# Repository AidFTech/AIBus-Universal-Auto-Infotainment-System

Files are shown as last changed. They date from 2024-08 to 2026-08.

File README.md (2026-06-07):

# AidF AIBus Universal Car Audio System

***Disclaimer:*** *"AIBus" refers to the bus standard used by the devices in this project to communicate with each other. It is a play on words of AidF and BMW IBus. This project does not use or contain any material created by artificial intelligence.*

The goal of this project is to create a more or less universal car stereo system with the ability to retain all external OEM features, such as CD changers, Sirius tuners, and non-radio displays (e.g. audio screens on the cluster). It adds Apple CarPlay and Android Auto through a Carlinkit for music and navigation. At the heart of this system is the AIBus interface, based heavily on BMW's IBus, to allow all components to communicate with each other. The principal components, which can be used in any vehicle, are the Raspberry Pi navigation computer and the Arduino radio tuner. The screen is a separate module and may be vehicle-specific or universal. All vehicle-specific/OEM components communicate with the system via one or more translator modules.

This is an ongoing project and I am a relatively new embedded programmer- any tips would be appreciated!

Thanks to Ted and [Bluebus](https://github.com/tedsalmon/BlueBus.git) for the inspiration!

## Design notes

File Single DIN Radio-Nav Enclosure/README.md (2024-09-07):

# Single DIN Radio/Nav Enclosure

Single-DIN enclosure for the radio, phone module, and Raspberry Pi nav computer.

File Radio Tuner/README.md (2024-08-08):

# AidF AIBus Radio Tuner
The universal radio tuner and source switch. Identified with AIBus ID 0x10. When finished, this device will be able to switch and output analog or digital audio from any source in the car. Full-range FM and AM tuning is supported via the Skyworks Si4732 with the option for 12 FM an 6 AM presets.

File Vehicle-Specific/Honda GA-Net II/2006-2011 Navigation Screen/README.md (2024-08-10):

# 2006-2011 Navigation Screen
This component uses the base, tilt motor, and button pannel of the navigation screen from a 2006-2011 Civic for a monitor. It will fit in any vehicle with a double-DIN opening, and allows for an audio accessory (e.g. CD changer or tape deck) in the top DIN slot, revealed by the screen tilting forward.

***This component is still a work in progress.***

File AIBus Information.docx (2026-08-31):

# AidF AIBus

# Basics

AIBus works similar to BMW’s I-BUS, but is balanced and runs at 115200. The structure is virtually identical.

The structure is as follows:

- Source Device ID: 1B, ID of the source device.
- Length: 1B, includes all following bytes.
- Destination Device ID: 1B, ID of the destination device (0xFF if broadcast).
- Data: Length given in the Length bytes, message.
- XOR Checksum: 1B, a simple XOR of all bytes in the message.

# Radio

  ID 0x10
  Messages:

Source | Length | Destination | Data Example | Interpretation
10 | 3 | FF | 04 E6 10 | Sent to all audio devices when the radio is first connected. May also be sent to individual sources as a “repeat.”
Any | 3 | 10 | 01 01 xx | Audio device “handshake.” Similar to Honda’s. Byte xx indicates device ID. May have a fourth byte to indicate subsource count.
Any | 2 | 10 | 01 02 | Similar audio device “handshake,” indicates that the device has already made contact but needs to add extra “sub-sources.” (e.g. XM1, XM2)
Any | Varies | 10 | 01 22 nn [...] | Short name of the audio device, sub-source nn.
Any | Varies | 10 | 01 23 nn [...] | Name of the audio device, sub-source nn.
10 | 3 or 4 | Any | 40 10 xx nn | Function change, xx indicates the ID of the device that is selected. A device can also send this message to request control (e.g. if a tape is loaded), the radio will send it back if it is accepted. If the source has multiple modes, nn is the mode.
10 | 3 | Any | 40 01 xx | Tells the source that device xx has text control. This control is automatically relinquished when the source receives a 40 10 message.
Any | 3 or 4 | 10 | 10 10 xx nn | Request for control, i.e. if a tape or disc is loaded.
10 | 3 | Any | 70 10 xx | Redundant heartbeat message to let device xx know it is still the selected source.
Any | 2 | 10 | 60 10 | Request for the currently selected source.
Any | 2 | 10 | 60 11 | Request for the current source with text control.
01, 57 | 2 | 10, 57, 3B | 1D nn | Set whether this device should be sending clock data. If nn is 00, stop sending clock messages. Otherwise: - |01: Start sending clock messages. - |02: Send clock messages but don’t automatically set the clock. - |04: Send clock right now if able and set. - |80: Send messages in 12h format.
Any | 4 | 10 | 33 06 xx yy | Set maximum volume to xx yy.
10 | 4 | 6A | 32 06 xx yy | Change volume to 2B value xx yy.
10 | 4 | 6A | 32 0A xx yy | Change the treble to xx yy.
10 | 4 | 6A | 32 0B xx yy | Change the bass to xx yy.
10 | 4 | 6A | 32 10 xx yy | Change the balance to xx yy- the value is formatted as an int16_t.
10 | 4 | 6A | 32 11 xx yy | Change the fade to xx yy.
1, 7 | 2 | 10 | 71 pp | Screen monitor enabled/disabled. If disabled, the radio should request all controls. Can also be sent to the computer to request the monitor on.

# CD Changer

  ID 0x06
  Messages:

Source | Length | Destination | Data Example | Interpretation
06 | 8 | 10, 11 | 39 00 pp 00 3F 00 dd tt | Disc and track, indicated by dd and tt, respectively. Whether the CD is playing is indicated by pp, pp = 02 if not playing, 09 if playing, 08 if seeking.
06 | 5 | 10, 11 | 3B 00 00 ss ss | Current track time. Bytes ss ss are a 16-bit representation of the total seconds.
06 | Varies | 10, 11 | 23 61 bb [...] | Song title in ASCII. Byte bb indicates the number of bytes per character, 1 or 2.
06 | Varies | 10, 11 | 23 62 bb [...] | Artist name in ASCII, same format as title.
06 | Varies | 10, 11 | 23 63 bb [...] | Album name in ASCII, same format as title.
10 | 3 | 06 | 30 00 00 | Query the CD player for status.
10 | 3 | 06 | 30 01 00 | Trigger pause/resume.
10 | 3 | 06 | 30 03 00 | Trigger normal play (if FF/FR is in use).
10 | 3 | 06 | 38 04 00 | Trigger fast forward.
10 | 3 | 06 | 38 04 01 | Trigger fast reverse.
10 | 3 | 06 | 38 06 0n | Go to disc n.
10 | 3 | 06 | 38 06 10 | Go to the previous disc.
10 | 3 | 06 | 38 06 20 | Go to the next disc.
10 | 3 | 06 | 38 06 0n | Go to disc n.
10 | 3 | 06 | 38 07 nn | Toggle scan mode: - 00: Off - 01: On - 10: Toggle
10 | 3 | 06 | 38 08 nn | Toggle random mode: - 00: Off - 01: Random Disc - 02: Random All - 10: Toggle
10 | 3 | 06 | 38 09 nn | Toggle repeat mode: - 00: Off - 01: Repeat Track - 02: Repeat Disc - 10: Toggle
10 | 3 | 06 | 38 0A 00 | Go to the next track.
10 | 3 | 06 | 38 0A 01 | Go to the previous track.
10 | 3 | 06 | 38 0B nn | Go to track nn.

# Nav Computer

  ID 0x01
  Audio Screen Messages:

Source | Length | Destination | Data Example | Interpretation
10 | 3 | 01, 8E | 26 vv mm | Display a volume bar at the top of the screen showing volume vv out of mm.
10, 8E | 3 | 01 | 27 30 26 | Open the audio window.
10 (or audio source) | 3 | 01 | 20 60 nn | Clear area nn. Use FF to clear all areas. Note, for all 2x messages below, follow with ||10 to refresh the screen.
10 (or audio source) | 3 | 01 | 20 61 nn | Clear subtitle area nn. Use FF to clear all subtitle areas.
10 (or audio source) | 3 | 01 | 20 62 nn | Clear function key nn. Use FF to clear all function keys.
10 (or audio source) | 3 | 01 | 20 6B nn | Clear button nn. Use FF to clear all buttons.
10 (or audio source) | 2 | 01 | 20 6F | Clear the entire audio screen.
10 (or audio source) | Varies | 01, 8E | 22 61 […] | Write text to the headerbar to be displayed briefly. Can also be sent from the navigation computer to the phone mirror.
10 (or audio source) | Varies | 01 | 23 60 nn [...] | Write text to the main area indicated by nn. Only valid if the audio screen is visible.
10 (or audio source) | Varies | 01 | 23 61 nn [...] | Write text to the subtitle area indicated by nn. Only valid if the audio screen is visible.
10 (or audio source) | Varies | 01 | 23 62 nn [...] | Write text to the bottom function key nn. Second nibble indicates button 1-6.
10 (or audio source) | Varies | 01 | 23 6B nn [...] | Write text to on-screen button 1-3. If the text is cleared, the button is unused.
10 (or audio source) | 2 | 01 | 23 6F | Refresh the audio screen.
57 | 3 | 01 | 2 0 0 | Emergency shutdown for the computer.

  Menu Messages:

Source | Length | Destination | Data Example | Interpretation
Any | Varies | 01 | 2B 50 nn ll xx xx yy yy ww ww hh hh […] | Create a new menu with nn rows. Bit 7 is 1 if the menu “loops.” Menu length is defined by ll, x and y coordinates are given by xx and yy. Bytes ww and hh define width and height of each entry. May be followed by the menu title or subtitle.
Any | Varies | 01 | 2B 51 nn […] | Add menu entry at position nn. If the menu has already been defined, this changes the entry.
Any | 3 | 01 | 2B 52 nn | Menu is complete, draw it with nn selected.
Any | Varies | 01 | 2B 53 […] | Change the menu title.
Any | Varies | 01 | 2B 54 nn pp mm ss […] | Add slider at position nn. Slider position is defined as pp out of total mm. Byte ss is 1 if the slider is selected.
01 | Varies | Any | 2B 55 […] | A request for a menu with the specified keyword.
01 | Varies | Any | 2B 56 […] | A request for whether a menu with the specified keyword exists.
Any | 2 | 01 | 2B 56 | A reply to the above.
01 | Varies | Any | 2B 57 […] | A request for a menu with the specified keyword and the name of that menu.
Any | Varies | 01 | 2B 57 […] | A reply to the above.
Any | Varies | 01 | 2B 5A nn ll xx xx yy yy ww ww hh hh […] | Create an audio-related menu defined as above. Note that this does not create a menu to be shown on the normal audio screen, it creates a setting overlay menu.
Any | 2 | 01 | 2B 40 | Clear the menu. Clear an audio menu if 4A.
Any | 2 | 01 | 2B 42 | Query to the nav computer regarding whether a menu can be drawn.
01 | 2 | Any | 2B 40 | The menu was cleared, or a menu cannot be drawn.
01 | 2 | Any | 2B 42 | A menu can be drawn, sent after the destination device sends the same message.
01 | 2 | Any | 2B 45 | Request for the settings menu.
10 or 1 | 2 | Any Source | 2B 4A | Request for the audio menu. Typically, this is sent from 1 to 10, then 10 to the source.
1 | 2 | C8 | 2B 4C | Request for the phone menu.
01 | 3 | Any | 2B 60 nn | Entry nn was selected.
01 | 3 | Any | 2B 6A nn | Main audio screen entry nn was selected.
01 | 3 | C8 | 2B 6C nn | Phone screen entry nn was selected.

  Vehicle Information Messages:

Source | Length | Destination | Data Example | Interpretation
57 | 3 or 4 | 01 or FF | 11 aa bb | Preceded with A1 if sent to FF. Light status, as follows: - Byte aa: - Bit 7: Auto Headlights - Bit 6: Right Turn Signal - Bit 5: Left Turn Signal - Bit 4: Front Fog Lights - Bit 3: Parking Lights - Bit 2: High Beams - Bit 1: Low Beams - Bit 0: DRLs - Byte bb: - Bit 7: Reverse Lights - Bit 6: Rear Fog Lights - Bit 5: Taillights - Bit 4: License Plate Lights - Bit 3: Off Road Lights - Bit 2: Bed Light

Navigation Messages:

Source | Length | Destination | Data Example | Interpretation

  01, 8E
  Varies
  11, 57
  7F 04 en an st sp sr sr […]
  Next turn event. Typically, byte an indicates the turn angle. 00=12:00 and the direction is spun counterclockwise. So a value of 0x40 indicates due left, etc. Byte en indicates the entry angle. Byte st indicates the step number. Byte sp indicates special instructions as follows, in decimal:
- 0: Normal Turn
- 1: Destination
- 2: Toll Booth
- 3: Ferry
- 4: Train
- 5: Enter Traffic Circle
- 6: Leave Traffic Circle, an indicates exit number.
- 7: Enter and leave traffic circle, an indicates exit number.
- 8: Make a U-turn, left
- 9: Make a U-turn, right
- 10: Merge Left
- 11: Merge Right
- 12: Waypoint
  Bytes sr indicate intersection design. Bit 0 of this cluster indicates a street at 12:00, each following bit indicates a street counterclockwise from there.

01, 8E | Varies | 11, 57 | 7F 05 nn rr […] | Next turn distance. Byte nn defines units (normally sent in m, bit 7 is high if km, bit 6 if mi, bit 5 if yd, and bit 4 if ft), and number of decimal places (bits 3-0). Byte rr indicates how to render a navigation bar.
8E | 3 | 01 | 7F 06 pp | Mute/unmute audio for a nav prompt. If pp!=0, mute.

Camera Messages

Source | Length | Destination | Data Example | Interpretation
57, 1 | 3 | 61 | 48 61 nn | Turn the camera on/off, off if nn==0. Otherwise the number determines which camera to use if multiple are present. This message can be sent by 61 to switch the nav system to display the camera.
61 | Varies | 1, 57 | 2C 3B […] | List of supported cameras/features, defined as follows: - 01: Rear View - 02: Left Side View - 03: Right Side View - 04: Front View - 05: Rear View Zoomed - 06: Rear Panoramic - 07: 360° from Top - 08: Bed (truck) - 80: Trajectory - 81: Distance Markers
Any | 2 | 61 | 2C F0 | Request for supported cameras and features.
61 | Varies | 1 | 3C nn […] | Cameras supported in the current view for switching purposes. Byte nn indicates the selected camera.
57 | 2 | 1 | 36 nn | Steering angle for trajectory display. 00 indicates do not display, 80 indicates that the wheel is centered.
57, 61 | 9 | 1 | 37 w1 w1 w2 w2 y1 y1 y2 y2 | Distance/trajectory position. Defined as top width, bottom width, top position, and bottom position. Always centered.
61 | Varies | 1 | 25 57 61 […] | Camera warning message to display at the bottom of the screen. If not specified, the default “Please Check Surroundings for Safety” is used.
61 | Varies | 1 | 25 57 62 […] | Camera video path.

# Screen

ID 0x07

Messages:

Source | Length | Destination | Data Example | Interpretation
07 | 3 | 01 | 30 nn tt | Push or release button nn. Byte tt defines behavior as follows: - 00: Pressed - 40: Held - 80: Released Button Definitions: - 06: Volume Knob - 07: Navigation Knob - 0A: Voice Command - 0B: Phone Send - 0C: Phone End - 11: Preset 1 - 12: Preset 2 - 13: Preset 3 - 14: Preset 4 - 15: Preset 5 - 16: Preset 6 - 20: Home - 21: Eject - 23: Source - 24: Skip Down - 25: Skip Up - 26: Audio - 27: Back - 28: Up - 29: Down - 2A: Left - 2B: Right - 30: FM - 31: AM - 32: Tape - 33: CD - 34: Aux - 35: XM - 36: FM/AM - 37: Tape/CD - 38: Media - 39: Scan - 44: Rewind - 45: FF - 46: Direction - 47: NR - 50: 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
07 | 3 | 01 | 32 nn dt | Knob turned. Byte nn = 06 if volume knob, 07 if navigation knob. Nibble t indicates number of steps, nibble d is 0 if the knob is rotated to the left, 1 if rotated to the right.
07 | 5 | 01 | 35 xx xx yy yy tt | Touch event at xx yy. Byte tt is defined as above.
07 | 2 | 01 | 38 nn | Screen status. Byte nn = 00 if screen is closed, 01 if screen is opening, 02 if open, 03 if closing. FF if the screen cannot move.
01, 10 | 2 | 07 | 38 nn | Byte nn = 0, close the screen. If 2, open the screen.
07 | 4 | 01, 10 | 47 xx yy cc | Auxiliary screen of dimensions xx yy is present. Byte cc is formatted as follows: - Bit 4: RGB Supported - Bit 3: Negative Mode - Bit 2: Dual Mode Supported
01, 10 | Varies | 07 | 27 hh vv […] | Print message to the auxiliary screen in standard monospace at horizontal indentation hh and vertical indentation vv.
01, 10 | Varies | 07 | 2E ss […] | Print message to the auxiliary screen in segmented form. Start at segment ss.
01 | 2 | 07 | 10 pp | Turn off display if pp is 00, on if pp is 11.
Any | 3 | FF | 77 ss nn | A “Status” message sent every 5s. If receiver ID is FF, acknowledgment is not required. If this message stops, all screen controls default to the navigation computer. If nn is ||20, audio controls (volume, preset buttons, source button, and all source controls unless they are requested by another device) are passed from the screen to the sending device (address ss). If ||80, “source” controls are passed to the device (seek/skip, direction control, and rewind/FF, and info). If ||10, all screen controls are passed (can only be sent by the radio).
7 | Varies | Any | 31 30 nn […] | A list of all buttons present on the screen. The bytes sent are the bytes that the buttons would trigger. All devices that can send messages to the screen can receive this message. Byte nn is ||2 if there is a selection wheel present, ||4 if a volume knob is present, ||8 if a tuning knob is present, and ||1 if touch capabilities are present. ||10 if function buttons are in a straight line at the bottom of the screen.
Any | 2 | 7 | 31 30 | A request for the screen buttons.
Any | 4 | 7 | 33 rr nn tt | Request to forward a button message to source rr. State tt and button nn are defined as above.
10 | 2 | 7 | 34 ss | Radio is on/off. Turn AidF logo on/off. Byte ss is 00 if off, 01 if on.
Any | 2 | 7 | 3E F0 | Request for screen EDID data.
7 | 129 | Any | 3E […] | EDID message.

# Custom iMID

ID 0x11

Messages:

Source | Length | Destination | Data Example | Interpretation
11 | 4 | Any | 3B 23 ww hh | Announcement that a custom text field is available, of ww characters per line and hh lines. This message can be sent to FF.
11 | Varies | Any | 3B 57 […] | Announcement that an OEM text field is available. This is followed by the sources available in AIBus form (e.g. 0x10 for radio, etc.).
Any | 3 | 11 | 04 E6 3B | Request for data sent with 3B.
Any | Varies | 11 | 20 60 nn […] | Clear rows indicated by nn. There may be multiple.
Any | Varies | 11 | 23 60 xx yy […] | Write a custom message at space xx and line yy.
10 | 4 | 11 | 40 10 ss uu | Change OEM display to source ss, subsource uu.
11 | 2 | 10 (or source) | 60 11 | A request for the radio to send the source name to the IMID.
11 | 2 | 10 (or source) | 60 10 | A request for the radio to send OEM source data to the IMID.
10 | 6 | 11 | 67 rr rr pp ss hh | FM or AM frequency rr, decimal point position pp. Byte ss is defined as follows: - 0x: Mono - | 1x: Stereo - | 2x: HD1 - | 4x: HD2 - | 6x: HD3 - | 8x: Acquiring HD First nibble defines preset. Byte hh indicates the preceding letter of the frequency in Hz (e.g. 0x4D for M, 0x6B for k).
10 | Varies | 11 | 63 60 […] | Call sign.
10 | Varies | 11 | 63 61 […] | Chunk RDS text.
10 | Varies | 11 | 63 62 […] | Full RDS text.
10 | 3 | 11 | 62 vv mm | Display a volume on screen, vv out of mm. This is sent regardless of the IMID structure.

# Tape Deck

ID 0x13

Messages:

Source | Length | Destination | Data Example | Interpretation
13 | 4 | 10 | 31 pp dd nn | Play status. Byte pp is defined as follows: - 02 = Play - 05 = Rewind - 04 = FF - 07 = Reverse Search - 06 = Forward Search - 10 = Loading - 11 = Ejecting - 00 = Tape Out Byte dd is defined bitwise: - Bit 6: Reverse Mode - Bit 5: Repeat On - Bit 1: NR On - Bit 0: CrO2 tape Byte nn indicates the number of tracks that are being searched. Only read if pp = 07 or 06.
10 | 2 | 13 | 28 00 | Query for tape deck status.
10 | 2 | 13 | 28 01 | Trigger direction change.
10 | 3 | 13 | 28 04 00 | Toggle fast forward.
10 | 3 | 13 | 28 04 01 | Toggle fast reverse.
10 | 4 | 13 | 28 07 00 nn | Toggle forward search. Byte nn indicates the number of tracks that are being searched.
10 | 4 | 13 | 28 07 01 nn | Toggle reverse search. Byte nn indicates the number of tracks that are being searched.
10 | 2 | 13 | 28 09 | Toggle repeat mode.
10 | 2 | 13 | 28 0A | Toggle NR.

# Sirius Tuner

ID 0x19

Messages:

Source | Length | Destination | Data Example | Interpretation
19 | 5 | 10, 11 | 39 00 hh hh pp | The tuner is set to channel hh and preset pp. If pp|=0x80, the signal was lost. If pp|=0x40, the channel is not available.
19 | Varies | 10, 11 | 23 61 bb [...] | Song title in ASCII. Byte bb indicates the number of bits per character, 1 or 2.
19 | Varies | 10, 11 | 23 62 bb [...] | Artist name in ASCII, same format as title.
19 | Varies | 10, 11 | 23 63 bb [...] | Channel name in ASCII, same format as title.
19 | Varies | 10, 11 | 23 64 bb [...] | Genre in ASCII, same format as title.
10 | 2 | 19 | 30 00 | Request for tuner status.
10 | 3 | 19 | 38 04 00 | Go to the next channel.
10 | 3 | 19 | 38 04 01 | Go to the previous channel.
10 | 3 | 19 | 38 05 hh hh | Go to channel hh.
10 | 3 | 19 | 38 06 pp | Go to preset channel pp. Numbers higher than 6 can be used for XM2.
10 | 3 | 19 | 38 07 00 | Increment the preset channel.
10 | 3 | 19 | 38 07 01 | Decrement the preset channel.
10 | 3 | 19 | 38 0A 00 | Go to the next category.
10 | 3 | 19 | 38 0A 01 | Go to the previous category.
10 | 3 | 19 | 38 16 pp | Save current channel as preset pp.

# CANslator

ID 0x57

Messages:

Source | Length | Destination | Data Example | Interpretation
57 | 3 | FF | A1 02 kk | Key position kk. Defined as follows: - 00 = Off - 01 = Acc 1 - 02 = Acc 2 - 03 = Cranking - 04 = Engine On Byte kk is ||10 if the key (or fob) is in the ignition, ||20 if the car has pushbutton start.
57 | 4 | FF | A1 10 ii nn | Illumination brightness, sent every few seconds (or upon change) if the appropriate CAN message is present. Brightness is given as ii, nn is defined as 00 if the system is in day mode, 80 if in night mode; ||1 if illumination should be on.
57 | 4 | FF | A1 11 aa bb | Headlight status, as defined above.
57, 3B, 10 | 6 | FF | A1 1F 01 hh mm ss | Time. Hour, minute, and second. Always 24h. If byte hh is |80, display time as 12h. If |40, time is being set automatically.
57, 3B, 10 | 7 | FF | A1 1F 02 yy yy mm dd | Date. Year, month, date.
57 | Varies | FF | A1 1F 03 nn tt […] | Outside temperature. Byte nn defines units (bit 7 is high if Fahrenheit), number of decimal places (bits 6-4), and number of bytes (bits 2-0). Bit 3 is high if negative.
57 | Varies | FF | A1 1F 04 nn tt […] | Vehicle speed. Byte nn defines units (bit 7 is high if mph), number of decimal places (bits 6-4), and number of bytes (bits 3-0).
57 | Varies | FF | A1 1F 05 nn tt […] | Coolant temperature. Byte nn defines units (bit 7 is high if Fahrenheit), number of decimal places (bits 6-4), and number of bytes (bits 2-0). Bit 3 is high if negative.
57 | Varies | FF | A1 1F 06 nn vv […] | Battery voltage. Byte nn defines number of decimal places (bytes 7-4) and number of bytes (bits 2-0).
57 | Varies | FF | A1 1F 07 nn rr […] | Vehicle range. Byte nn defines units (bit 7 is high if miles), number of decimal places (bits 6-4), and number of bytes (bits 2-0).
57 | Varies | FF | A1 1F 08 nn mm […] | Instantaneous fuel economy. Byte nn defines units (bits 7 and 6 are defined as follows: 11 indicates Imperial mpg, 10 indicates US mpg, 01 indicates km/L, 00 indicates L/100km), bit 5 is high if the fuel economy is undefined, remaining bits define number of decimal places.
57 | Varies | FF | A1 1F 09 nn mm […] | Average fuel economy, defined as above.
57 | Varies | FF | A1 1F 0A nn mm […] | Trip timer. Byte nn defines whether this is given in seconds or minutes- bit 7 is high if minutes. Other bits define byte count.
57 | Varies | FF | A1 1F 0B nn dd […] | Trip distance. Byte nn defines units (bit 7 is high if miles), number of decimal places (bits 6-4), and number of bytes (bits 3-0).
57 | Varies | FF | A1 1F 0C nn ss […] | Cruise set speed. Byte nn defines units (bit 7 is high if mph), number of decimal places (bits 6-4), and number of bytes (bits 3-0). If all zeroes, cruise control is off.
57 | 4 | FF | A1 12 nn gg | Current gear. Byte nn defines the type of transmission: - 00: Manual - 01: Automatic (traditional) - 02: Semiautomatic - 03: DCT/DSG - 04: SMG - 05: CVT - 06: IVT - 07: eCVT - 08: EV Direct Drive - 09: Direct Drive with Engine Clutch (series-parallel hybrid) Byte gg defines the gear- last nibble defines the actual gear number (or ratio percentage with CVT). First nibble: - 0: Neutral - 1: Drive - 2: Reverse - 4: Park - 8: Low Gear - 9: Manual Mode Obviously, for a manual car, only Reverse and Neutral are used.
57 | 3 | FF | A1 13 ss | Signal lights and parking brake. - Bit 0: Left Turn Signal - Bit 1: Right Turn Signal - Bit 2: Hazards Active - Bit 3: Brake Lights - Bit 4: Parking Brake
57 | 3 | FF | A1 14 nn | Auto stop on/off. If nn is nonzero, auto stop is active. If nn is 1, auto stop is disabled.
57 | 5 | FF | A1 33 01 ss xx | Hybrid system is present. Byte ss is defined as follows: - 01: Series Hybrid (e.g. Chevrolet) - 02: Parallel Hybrid (e.g. Honda IMA, Hyundai, Kia) - 03: Series-Parallel Hybrid (e.g. newer Honda) - 04: Power-Split Hybrid (e.g. Ford, Toyota, Nissan) - |10: Charge/Assist Meter Additional features in byte xx: - |01: Plug - |02: Rear Electric Motor - |04: Front Electric Motor (if RWD) - |10: Electric A/C - |20: Conventional A/C - |40: Electric Heater
57 | 6 | FF | A1 33 02 aa bb cc | Hybrid power flow. Byte aa: - |01: Battery to Electric Motor - |02: Electric Motor to Battery - |04: Electric Motor to Battery, regenerative - |08: Electric Motor to Wheels - |10: Wheels to Electric Motor - |20: Engine to Wheels - |40: Engine to Electric Motor - |80: Plug to Battery Byte bb indicates battery charge level out of 255. Byte cc, if present, indicates charge/assist, centered at 0x7F.
57 | 3 | FF | A1 43 dd | Door status. Byte dd is defined as follows: - 20: Hood - 10: Trunk/Liftgate - 08: Driver Door - 04: Front Passenger Door - 02: Left Rear Door - 01: Right Rear Door If the byte |= 0x80, the door is being opened to turn the vehicle off.
01 | 2 | 57 | 45 nn | Request for vehicle information. Byte nn is defined as follows: - 01: Fuel Economy - 02: Odometer - 03: Outside Temperature - 04: Vehicle Speed
57 | Varies | 01 | 46 nn yy […] | Vehicle information with byte nn defined as above. Placed in grid yy- column is defined by bit 7. Row is defined by remaining bits. Contains the string that will be printed to screen.
01 | 2 | 57 | 49 1F | A request for all supported “common” vehicle sensors.
57 | 3 | 01 | 49 aa bb | Supported common parameters. Defined as: Byte aa: - 80: Vehicle Specific Sensors - 8: Remaining Distance - 4: Remaining Time - 2: Trip Distance - 1: Range Byte bb: - 80: Gear - 40: Cruise Speed - 20: Trip Timer - 10: Trip Average Economy - 8: Instantaneous Economy - 4: Coolant Temperature - 2: Outside Temperature - 1: Battery Voltage
Any | 2 | 57 | 4A 18 | A request for key position, doors open, and brightness information to be sent to the sending device upon a change.
Any | 2 | 57 | 4A 1E | A request for info such as key position, doors open, time/date if CANslator is counting, etc. All data is resent.
Any | 2 | 57 | 4A 1F | Similar to above, but sent if the system should assume the sending device has just woken up/is preparing to power off.
57 | 1 | 01 | 4F | Refresh printed data.

# Climate Control Translator

  ID 0x51
  Messages:

Source | Length | Destination | Data Example | Interpretation
51 | 6 | 1 | 25 01 41 tt ff mm | Introductory climate message containing the number of temperature zones (tt), fan zones (ff), and mode zones (mm). Byte 2 is |0x10 if climate control is automatic. For example, a 9th gen Civic would send 25 01 51 01 01 01. An E39 would send 25 01 51 02 01 01, and an E38 would send 25 01 51 02 02 02. Zone 1 is interpreted as the driver’s seat, zone 2 as the passenger, zone 3 as the rear.
51 | 5 | 1 | 25 02 mm xx uu | Minimum (mm) and maximum (xx) temperature. Temperature units uu: 00 if Celsius, 01 if Fahrenheit.
51 | 3 | 1 | 25 03 ff | Number of possible fan speeds.

  51
  Varies
  1
  25 11 01 nn tt ff mm 02 nn […]
  Currently set temperature (tt), fan speed (ff), and mode (mm) for each zone. Byte nn is interpreted as follows:
- Bit 0: Automatic Fan Speed
- Bit 1: Automatic Mode
- Bit 2: Automatic Temperature Control
- Bit 3: Automatic Recirc (zone 1 only)
- Bit 4: Automatic A/C (zone 1 only)
- Bit 7: System On

Mode is interpreted as follows:

- Bit 0: Vent
- Bit 1: Floor
- Bit 2: Defrost
- Bit 3: Upper Vent (Volvo, BMW, Mercedes)

Bytes are always sent in the order shown. If the vehicle has multiple zones for temperature but not fan speed or mode, for example (as predetermined), only the temperature byte is sent.

If the fan speed or mode are unknown with the climate control in automatic mode, those bytes can be null.
51 | Varies | 1 | 25 04 nn […] | Lists all available mode combinations. Byte nn determines if any modes can be turned on/off independently (e.g. Volvo, BMW, 2010s Ford).
51 | Varies | 1 | 25 05 zz nn […] | Works like 25 04 but applies to zone zz.
51 | 4 | 1 | 25 06 zz ff | Number of possible fan speeds for zone zz.
51 | 6 | 1 | 25 07 zz mm xx uu | Works like 25 02 for zone zz.

# Phone Module

  ID 0xC8
  Note: All audio data is handled like the CD changer.
  Messages:

Source | Length | Destination | Data Example | Interpretation
Any | 1 | C8 | 12 | Request for Bluetooth MAC address.
C8 | 7 | Any | 12 […] | The Bluetooth MAC address.
C8 | 3 | 01, 10 | 21 01 00 | Incoming call. No further information.
C8 | Varies | 01, 10 | 21 01 03 […] | Incoming call. Number is written in ASCII by following bytes.
C8 | Varies | 01, 10 | 21 01 04 […] | Incoming call. Contact name is written by following bytes.
C8 | Varies | 01, 10 | 21 11 03 […] | Outgoing call. Number is written in ASCII by following bytes.
C8 | Varies | 01, 10 | 21 11 04 […] | Outgoing call. Contact name is written by following bytes.
C8 | 3 | 01 | 21 00 01 | Force the phone window open.
C8 | 3 | 10 | 21 06 01 | Stop audio.
C8 | 3 | 10 | 21 06 00 | Resume audio.
01 | Varies | C8 | 21 01 03 […] | Dial the following number in ASCII.
01 | 3 | C8 | 21 01 01 | Accept an incoming call.
01 | 3 | C8 | 21 01 02 | Reject an incoming call or hang up.
C8 | Varies | 01 | 21 A5 zz […] | Write the text that follows to the phone window, zone zz. Group is defined by the first nibble, area is defined by the second. Formatted similar to the audio window sans function buttons.
C8 | Varies | 10, 11 | 23 64 bb […] | Phone name in ASCII.

# Steering Wheel Controls

ID 0x6F

Messages:

Source | Length | Destination | Data Example | Interpretation
6F | 3 | 10 | 30 nn tt | Push or release audio button nn, formatted exactly as from ID 7, with the following exceptions: Volume control: nn=6, tt |= 1 if volume up, tt |= 2 if volume down.

# GPS Antenna

ID 0x3B

Messages:

Source | Length | Destination | Data Example | Interpretation
3B | 14 | 01, 8E | 55 ss td td tm ts tf nd nd nm ns nf al al | GPS antenna reading with strength ss. Other bytes are interpreted as: - Bytes td, tm, ts, tf: Latitude degrees, minutes, and seconds. Group td is signed. Byte tf indicates fractional seconds. Bit 7 of tm is high if the latitude is negative but the degree number is zero. - Bytes nd, nm, ns, nf: Longitude degrees, minutes, and seconds. Group nd is signed. Byte nf indicates fractional seconds. Bit 7 of nm is high if the longitude is negative but the degree number is zero. - Bytes al: Altitude in meters.

# Android Auto Pi

ID 0x8E

Messages:

Source | Length | Destination | Data Example | Interpretation
01 | 3 | 8E | 48 8E nn | Turn off (nn = 0) or turn on (nn = 1) the AMirror interface.
8E | 3 | 01 | 48 01 nn | Same as above.
01 | Varies | 8E | 52 […] | Send a BASH command to the Pi.
8E | Varies | 01 | 52 […] | BASH command from the Pi.
8E | 2 | 01 | 60 20 | A request for colors, as defined below.
01 | 5 | 8E | 60 20 rr gg bb | Change background color to rgb. Normally sent when the Teensy display switches from day to night or the user changes the color.
01 | 5 | 8E | 60 21 rr gg bb | Change text color to rgb.
01 | 5 | 8E | 60 22 rr gg bb | Change header color to rgb.
01 | 5 | 8E | 60 23 rr gg bb | Change selection rectangle color to rgb.
01 | 5 | 8E | 60 24 rr gg bb | Change border color to rgb.
8E | 2 | 01, 10, 57, 11 | 30 pp | Type of phone connected. Byte pp: 03 = iPhone, 05 = Android.
8E | 2 | 10 | 39 pp | Play/pause status. Byte pp = 02 if playing, 00 if paused.
8E | 5 | 10, 01, 11 | 3B 00 00 ss ss | Current track time. Bytes ss ss are a 16-bit representation of the total seconds.
8E | Varies | 10, 01, 11 | 23 30 […] | Name of phone.
8E | Varies | 10, 01 | 23 60 [...] | Music app name in ASCII, if present.
8E | Varies | 10, 01, 11 | 23 61 [...] | Song title in ASCII.
8E | Varies | 10, 01, 11 | 23 62 [...] | Artist name in ASCII.
8E | Varies | 10, 01, 11 | 23 63 [...] | Album name in ASCII.
8E | Varies | 11 | 23 64 [...] | Music app name in ASCII (IMID version).
10 | 3 | 8E | 30 00 00 | Query Pi status.
10 | 3 | 8E | 30 01 00 | Trigger pause/resume.
10 | 3 | 8E | 30 01 10 | Force resume.
10 | 3 | 8E | 30 01 20 | Force pause.
10 | 3 | 8E | 38 0A 00 | Go to the next track.
10 | 3 | 8E | 38 0A 01 | Go to the previous track.
8E | 3 | FF | 77 8E nn | A “Status” message sent every 500ms. If nn is ||01, the video feed switches to the Pi. If the message is not sent or nn is 0, the feed switches back to the Teensy. If nn is ||10, screen controls are passed to the Pi (8E). If nn is ||20, audio controls are passed as well.
Any | Varies | 8E | 20 6s | Clears the overlay, zone defined by nibble s. If s == 0xF, all zones are cleared. If s == 0xE, all zones except the first are cleared.
Any | Varies | 8E | 23 6s […] | Print the following text to an overlay, zone defined by nibble s. Byte 1 |= 0x10 to activate the overlay.
8E, 01 | 2 | 01, 07 | 2C F0 | Request for screen/window dimensions.
01, 07 | 5 | 8E, 01 | 2C xx xx yy yy | Screen dimension response. Dimensions are given as xx, yy.

# Generic Messages

Source | Length | Destination | Data Example | Interpretation
Any | 1 | Any | 80 | Acknowledgment byte.
Any | Varies | Any | 91 nn ee | Split AIBus message of length nn, entry ee.
Any | 1 | Any | 01 | Ping (if not followed by any other bytes).
Any | 1 | Any | 92 | Resend last message or divided messages.
Any | 1 | FF | A0 | Poweroff announcement.

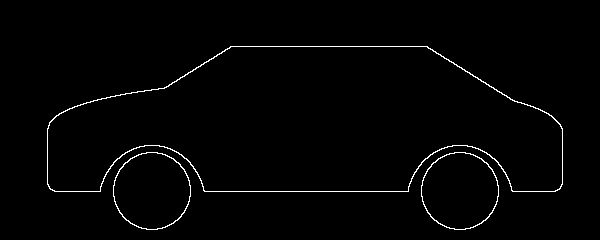
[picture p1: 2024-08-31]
Navigation Computer/Symbols/Car Silhouette Outline.png

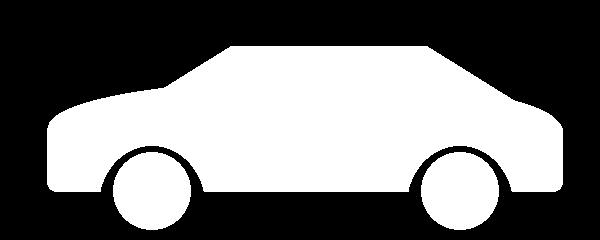
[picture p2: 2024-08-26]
Navigation Computer/Symbols/Car Silhouette.png

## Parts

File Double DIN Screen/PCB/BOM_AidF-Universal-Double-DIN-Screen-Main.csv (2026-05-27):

ID | Name | Designator | Footprint | Quantity | Manufacturer Part | Manufacturer | Supplier | Supplier Part | Price
1 | 0.1uF | C1,C2,C3,C5,C9,C10,C11,C14,C15,C18,C19,C20,C21,C24,C25,C28,C29,C30,C31,C37,C39,C40,C41,C42,C43,C44,C45,C46,C47,C48,C49,C50,C51,C62 | C0603 | 34 | 0603B104K101CT | Walsin Technology Corporation | Digi-Key | 1292-1392-1-ND
2 | 10nF | C4,C6,C16,C17,C22,C23 | C0603 | 6 | KGM15AR71H103KT | KYOCERA AVX | Digi-Key | 478-KGM15AR71H103KTCT-ND
3 | 470pF | C7,C8 | C0603 | 2 | CL10C471JB8NNNC | Samsung Electro-Mechanics | Digi-Key | 1276-1168-1-ND
4 | 47nF | C12,C13,C26,C27 | C0603 | 4 | GCJ188R71H473KA12D | Murata Electronics | Digi-Key | 490-5854-1-ND
5 | 22u | C32,C33,C34,C35,C36,C38 | C1210 | 6 | CL32B226KAJNFNE | Samsung Electro-Mechanics | Digi-Key | 1276-3391-1-ND
6 | 1uF | C52,C53,C54,C55,C56,C57,C58,C59,C60,C61 | C0603 | 10 | CC0603KRX5R8BB105 | YAGEO | Digi-Key | 311-1445-1-ND
7 | SD103AWS-TP | D1,D2,D3,D4,D8,D9,D10,D11 | SOD-323_L1.8-W1.3-LS2.6-FD | 8 | SD103AWS-TP | Micro Commercial Co | Digi-Key | SD103AWSTPMSCT-ND
8 | 5.6V | D5 | SOD-123_L2.7-W1.6-LS3.7-RD-A | 1 | MMSZ5232BT1G | onsemi | Digi-Key | MMSZ5232BT1GOSCT-ND
9 | 3.6V | D6 | SOD-123_L2.7-W1.6-LS3.7-RD-A | 1 | MMSZ4685-TP | Micro Commercial Co | Digi-Key | MMSZ4685-TPMSCT-ND
10 | 12V | D7 | SOD-123_L2.7-W1.6-LS3.7-RD-A | 1 | BZT52C12-TP | Micro Commercial Co | Digi-Key | BZT52C12-TPMSCT-ND
11 | FH12-40S-0.5SH(55) | FPC1 | FPC-SMD_FH12-40S-0.5SH-55 | 1 | FH12-40S-0.5SH(55) | Hirose Electric Co Ltd | Digi-Key | 26-FH12-40S-0.5SH(55)CT-ND
12 | FH28-60S-0.5SH(05) | FPC2 | FFC-SMD_60P-P0.50_FH28H-60S-0.5SH | 1 | FH28-60S-0.5SH(05) | Hirose Electric Co Ltd | Digi-Key | HFV160CT-ND
13 | SM02B-BHSS-1-TB | J1 | CONN-SMD_SM02B-BHSS-1-TB | 1 | SM02B-BHSS-1-TB(LF)(SN) | JST Sales America Inc. | Digi-Key | 455-2876-1-ND
14 | 20021311-00030T4LF | J2 | HDR-TH_30P-P1.27-V-F-R2-C15-S1.27 | 1 | 20021311-00030T4LF | Amphenol | Digi-Key | 609-3763-ND
15 | 1u | L3,L4,L5,L6,L9,L11,L12,L13 | L0603 | 8 | BLM18RK601SN1D | Murata Electronics | Digi-Key | 490-5227-1-ND
16 | Eject | LED1 | LED0603-RD | 1 | QBLP601-IW | QT Brightek (QTB) | Digi-Key | 1516-1057-1-ND
17 | Source | LED2 | LED0603-RD | 1 | QBLP601-IW | QT Brightek (QTB) | Digi-Key | 1516-1057-1-ND
18 | Audio | LED3 | LED0603-RD | 1 | QBLP601-IW | QT Brightek (QTB) | Digi-Key | 1516-1057-1-ND
19 | FM/AM | LED4 | LED0603-RD | 1 | QBLP601-IW | QT Brightek (QTB) | Digi-Key | 1516-1057-1-ND
20 | Tape/CD | LED5 | LED0603-RD | 1 | QBLP601-IW | QT Brightek (QTB) | Digi-Key | 1516-1057-1-ND
21 | Skip | LED6 | LED0603-RD | 1 | QBLP601-IW | QT Brightek (QTB) | Digi-Key | 1516-1057-1-ND
22 | Info | LED7 | LED0603-RD | 1 | QBLP601-IW | QT Brightek (QTB) | Digi-Key | 1516-1057-1-ND
23 | Tone | LED8 | LED0603-RD | 1 | QBLP601-IW | QT Brightek (QTB) | Digi-Key | 1516-1057-1-ND
24 | Home | LED9 | LED0603-RD | 1 | QBLP601-IW | QT Brightek (QTB) | Digi-Key | 1516-1057-1-ND
25 | Setup | LED10 | LED0603-RD | 1 | QBLP601-IW | QT Brightek (QTB) | Digi-Key | 1516-1057-1-ND
26 | Back | LED11 | LED0603-RD | 1 | QBLP601-IW | QT Brightek (QTB) | Digi-Key | 1516-1057-1-ND
27 | SI2347DS-T1-GE3 | Q1,Q2,Q3,Q4,Q7 | SOT-23-3_L2.9-W1.3-P1.83-LS2.4-BR-1 | 5 | SI2347DS-T1-GE3 | Vishay Siliconix | Digi-Key | SI2347DS-T1-GE3CT-ND
28 | 2N7002 | Q5,Q6,Q8 | SOT-23_L2.9-W1.3-P0.95-LS2.4-BR | 3 | DMN3404L-7 | Diodes Incorporated | Digi-Key | DMN3404LDICT-ND
29 | DMN67D8L-7 | Q9,Q10,Q11 | SOT-23-3_L3.0-W1.7-P0.95-LS2.9-BR | 3 | DMN67D8L-7 | Diodes Incorporated | Digi-Key | DMN67D8L-7DICT-ND
30 | 1k | R1,R2 | R0603 | 2 | RC0603FR-071KL | YAGEO | Digi-Key | 311-1.00KHRCT-ND
31 | 10k | R3,R4,R5,R6,R9,R10,R13,R14,R15,R16,R19,R20,R32,R33,R34,R64,R65,R66 | R0603 | 18 | RNCP0603FTD10K0 | Stackpole Electronics Inc | Digi-Key | RNCP0603FTD10K0CT-ND
32 | 47k | R7,R8,R11,R12 | R0603 | 4 | RC0603FR-0747KL | YAGEO | Digi-Key | 311-47.0KHRCT-ND
33 | 470 | R17,R18,R35 | R0603 | 3 | RC0603JR-07470RL | YAGEO | Digi-Key | 311-470GRCT-ND
34 | 150 | R21,R22,R23,R24,R25,R26,R27,R28,R29,R30,R31 | R0603 | 11 | RC0603FR-07150RL | YAGEO | Digi-Key | 311-150HRCT-ND
35 | 33 | R36,R37,R38,R39,R40,R41,R42,R43,R44,R45,R46,R47,R48,R49,R50,R51,R52,R53,R54,R55,R56,R57,R58,R59,R60,R61,R62,R63 | R0603 | 28 | WR06X330 JTL | Walsin Technology Corporation | Digi-Key | 1292-WR06X330JTLCT-ND
36 | 54.9 | R67 | R0603 | 1 | RC0603FR-0754R9L | YAGEO | Digi-Key | 311-54.9HRCT-ND
37 | 255 | R68 | R0603 | 1 | RC0603FR-07255RL | YAGEO | Digi-Key | 311-255HRCT-ND
38 | 59 | R69,R72 | R0603 | 2 | RC0603FR-0759RL | YAGEO | Digi-Key | 311-59.0HRCT-ND
39 | 52.3 | R70 | R0603 | 1 | RC0603FR-0752R3L | YAGEO | Digi-Key | 311-52.3HRCT-ND
40 | 221 | R71 | R0603 | 1 | RC0603FR-07221RL | YAGEO | Digi-Key | 311-221HRCT-ND
41 | 162 | R73 | R0603 | 1 | RC0603FR-07162RL | YAGEO | Digi-Key | 311-162HRCT-ND
42 | 36.5 | R74 | R0603 | 1 | RC0603FR-0736R5L | YAGEO | Digi-Key | 311-36.5HRCT-ND
43 | 43.2 | R75 | R0603 | 1 | RC0603FR-0743R2L | YAGEO | Digi-Key | 311-43.2HRCT-ND
44 | 237 | R76 | R0603 | 1 | RMCF0603FT237R | Stackpole Electronics Inc | Digi-Key | RMCF0603FT237RCT-ND
45 | 71.5 | R77 | R0603 | 1 | RC0603FR-0771R5L | YAGEO | Digi-Key | 311-71.5HRCT-ND
46 | TL1015AF160QG | SW1,SW2,SW3,SW4,SW5,SW6,SW7,SW8,SW9,SW10,SW11,SW12 | KEY-SMD_6P-L3.9-W2.9-LS4.5 | 12 | TL1015AF160QG | E-Switch | Digi-Key | EG4344CT-ND
47 | ATMEGA3209-AU | U1 | TQFP-48_L7.0-W7.0-P0.50-LS9.0-BL | 1 | ATMEGA3209-AU | Microchip Technology | Digi-Key | 150-ATMEGA3209-AU-ND
48 | NA556 | U2 | SOIC-14_L8.7-W3.9-P1.27-LS6.0-BL | 1 | NA556DR | Texas Instruments | Digi-Key | 296-21754-1-ND
49 | MCP4251-104E/SL | U3 | SOIC-14_L8.7-W3.9-P1.27-LS6.0-BL | 1 | MCP4251-104E/SL | Microchip Technology | Digi-Key | MCP4251-104E/SL-ND
50 | SN74LVC2G04DBVR_C19829671 | U4,U5,U14,U15 | SOT-23-6_L2.9-W1.6-P0.95-LS2.8-BR | 4 | SN74LVC2G04DBVR | Texas Instruments | Digi-Key | 296-13261-1-ND
51 | SN74LVC2G32DCUR | U6,U12 | VSSOP-8_L2.3-W2.0-P0.50-LS3.1-BR | 2 | SN74LVC2G32DCUR | Texas Instruments | Digi-Key | 296-13268-1-ND
52 | CD4013BM96 | U7,U13 | SOIC-14_L8.7-W3.9-P1.27-LS6.0-BL | 2 | CD4013BM96 | Texas Instruments | Digi-Key | 296-24347-1-ND
53 | 74HC123D-Q100,118 | U8,U11 | SOIC-16_L9.9-W3.9-P1.27-LS6.0-BL | 2 | 74HC123D-Q100,118 | Nexperia USA Inc. | Digi-Key | 1727-74HC123D-Q100,118CT-ND
54 | SN74AHC1G86DCKRE4 | U9,U10 | SC-70-5_L2.1-W1.3-P0.65-LS2.1-BL | 2 | SN74AHC1G86DCKRE4 | Texas Instruments | Digi-Key | 296-8750-1-ND
55 | MCP23S08-E/SO | U16,U17 | SOIC-18_L11.6-W7.5-P1.27-LS10.3-BL | 2 | MCP23S08-E/SO | Microchip Technology | Digi-Key | MCP23S08-E/SO-ND
56 | TFP401PZP | U18 | HTQFP-100_L14.0-W14.0-P0.50-LS16.0-BL-EP5.2 | 1 | TFP401PZP | Texas Instruments | Digi-Key | 296-9992-ND
57 | SN74LVC1G08DBVR | U19,U20,U23 | SOT-23-5_L3.0-W1.7-P0.95-LS2.8-BR | 3 | SN74LVC1G08DBVR | Texas Instruments | Digi-Key | 296-11601-1-ND
58 | SN74LVC2G04DCKR | U21 | SOT-363_L2.1-W1.3-P0.65-LS2.2-BL | 1 | SN74LVC2G04DCKR | Texas Instruments | Digi-Key | 296-13262-1-ND
59 | SN74LVC2G08DCTRE4 | U22 | MSOP-8_L2.9-W2.8-P0.65-LS4.0-BR | 1 | SN74LVC2G08DCTRE4 | Texas Instruments | Digi-Key | 296-13263-1-ND

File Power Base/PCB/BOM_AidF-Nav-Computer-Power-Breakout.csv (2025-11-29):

ID | Name | Designator | Footprint | Quantity | Manufacturer Part | Manufacturer | Supplier | Supplier Part | Price
1 | 47uF | C1 | C1206 | 1 | GRM31CR61E476ME44K | Murata Electronics | Digi-Key | 490-GRM31CR61E476ME44KCT-ND
2 | 0.1uF | C2,C32 | C0603 | 2 | 0603B104K101CT | Walsin Technology Corporation | Digi-Key | 1292-1392-1-ND
3 | 0.1u | C6,C14,C19,C22,C25,C34 | C0603 | 6 | 06035C104JAT2A | KYOCERA AVX | Digi-Key | 478-5778-1-ND
4 | 10u | C7,C8,C11,C12,C13,C20,C21,C26,C27,C28,C33 | C0805 | 11 | CL21A106KAYNNNG | Samsung Electro-Mechanics | Digi-Key | 1276-6454-1-ND
5 | 22u | C9,C10,C15,C16,C23,C24,C29,C30,C35,C36 | C1210 | 10 | CL32B226KAJNFNE | Samsung Electro-Mechanics | Digi-Key | 1276-3391-1-ND
6 | 100n | C31,C38 | C0603 | 2 | 06035C104JAT2A | KYOCERA AVX | Digi-Key | 478-5778-1-ND
7 | 10u | C37 | CAP-D5.0-F2.0 | 1 | ECA-1HM100I | Panasonic Electronic Components | Digi-Key | P10425CT-ND
8 | 33n | C39 | C0603 | 1 | GCM188R71H333KA55D | Murata Electronics | Digi-Key | 490-8025-1-ND
9 | 1uF | C43 | C0603 | 1 | CC0603KRX5R8BB105 | YAGEO | Digi-Key | 311-1445-1-ND
10 | 47uF | C44 | C1210 | 1 | GRM32EC81C476KE15K | Murata Electronics | Digi-Key | 490-16309-1-ND
11 | 18V | D1 | SOD-123_L2.8-W1.8-LS3.7-RD | 1 | BZT52C18-7-F | Diodes Incorporated | Digi-Key | BZT52C18-FDICT-ND
12 | SD103AWS-TP | D2,D4,D6,D11,D18,D20,D21,D22,D26 | SOD-323_L1.8-W1.3-LS2.6-FD | 9 | SD103AWS-TP | Micro Commercial Co | Digi-Key | SD103AWSTPMSCT-ND
13 | SK54A-LTP | D3,D5,D8,D10,D19 | DO-214AC_L4.3-W2.4-LS4.7-RD | 5 | SK54A-LTP | Micro Commercial Co | Digi-Key | SK54A-LTPMSCT-ND
14 | 3.6V | D7 | SOD-123_L2.7-W1.6-LS3.7-RD-A | 1 | MMSZ4685-TP | Micro Commercial Co | Digi-Key | MMSZ4685-TPMSCT-ND
15 | 2.7V | D12 | SOD-323_L1.7-W1.3-LS2.5-FD | 1 | BZX384-C2V7,115 | Nexperia USA Inc. | Digi-Key | 1727-4989-1-ND
16 | 5V | D13,D14,D17,D23 | SOD-323_L1.7-W1.3-LS2.7-RD-1 | 4 | BZT52C5V1S-TP | Micro Commercial Co | Digi-Key | BZT52C5V1S-TPMSCT-ND
17 | 1.8V | D15 | SOD-323_L1.7-W1.3-LS2.5-FD | 1 | BZX38450-C1V8-QX | Nexperia USA Inc. | Digi-Key | 1727-BZX38450-C1V8-QXCT-ND
18 | 3.6V | D16 | SOD-323_L1.7-W1.3-LS2.5-FD | 1 | BZX384-B3V6,115 | Nexperia USA Inc. | Digi-Key | 1727-3655-1-ND
19 | SK110-AQ | D24 | DO-214AC_L4.3-W2.7-LS5.2-RD | 1 | Z1SMA1 | Diotec Semiconductor | Digi-Key | 4878-Z1SMA1CT-ND
20 | MBR0530-TP | D25 | SOD-123_L2.7-W1.6-LS3.7-RD-1 | 1 | MBR0530-TP | MCC (Micro Commercial Components) | Digi-Key | MBR0530TPMSCT-ND
21 | PROGRAM | D27 | LED-TH_BD5.0-P2.54-FD | 1 | LTL-4233 | Lite-On Inc. | Digi-Key | 160-1130-ND
22 | 5A | F1 | FUSE-TH_01530008Z | 1 | 01530008Z | Littelfuse Inc | Digi-Key | F065-ND
23 | FH12-20S-0.5SH(55) | FPC1 | FPC-SMD_FH12-20S-0.5SH-55 | 1 | FH12-20S-0.5SH(55) | Hirose Electric Co Ltd | Digi-Key | HFJ120CT-ND
24 | HDR-F-2.54_1x10 | H1,H6,H8 | HDR-F-2.54_1X10 | 3 | RS1-10-G | Adam Tech | Digi-Key | 2057-RS1-10-G-ND
25 | HDR-F-2.54_1x8 | H2,H7,H9 | HDR-F-2.54_1X8 | 3 | RS1-08-G | Adam Tech | Digi-Key | 2057-RS1-08-G-ND
26 | HDR-F-2.54_1x5 | H3,H4 | HDR-F-2.54_1X5 | 2 | RS1-05-G | Adam Tech | Digi-Key | 2057-RS1-05-G-ND
27 | RS1-12-G | H5 | RS1-12-G | 1 | RS1-12-G | Adam Tech | Digi-Key | 2057-RS1-12-G-ND
28 | HDR-F-2.54_1x2 | H10,H13 | HDR-F-2.54_1X2 | 2 | RS1-02-G | Adam Tech | Digi-Key | 2057-RS1-08-G-ND
29 | HDR-F-2.54_1x4 | H11,H12 | HDR-F-2.54_1X4 | 2 | RS1-04-G | Adam Tech | Digi-Key | 2057-RS1-04-G-ND
30 | 1-770966-0 | J1 | CONN-TH_2P-P4.14_TE_1-770966-0 | 1 | 1-770966-0 | TE Connectivity AMP Connectors | Digi-Key | A32471-ND
31 | S12B-XADSS-N | J2 | CONN-TH_S12B-XADSS-N-LF-SN | 1 | S12B-XADSS-N | JST Sales America Inc. | Digi-Key | 455-S12B-XADSS-N-ND
32 | S02B-XASS-1(LF)(SN) | J3 | CONN-TH_P2.50_S02B-XASS-1-LF-SN | 1 | S02B-XASS-1(LF)(SN) | JST Sales America Inc. | Digi-Key | 455-S02B-XASS-1-ND
33 | S06B-XASK-1(LF)(SN) | J4 | CONN-TH_5P-P2.50_S06B-XASK-1-LF-SN | 1 | S06B-XASK-1(LF)(SN) | JST Sales America Inc. | Digi-Key | 455-4091-ND
34 | S08B-XADSS-N | J5 | CONN-TH_8P-P2.50_S08B-XADSS-N-LF-SN | 1 | S08B-XADSS-N | JST Sales America Inc. | Digi-Key | 455-S08B-XADSS-N-ND
35 | SJ2-35813A-SMT-TR | J6 | AUDIO-SMD_SJ2-35813A-SMT-TR | 1 | SJ2-35813A-SMT-TR | CUI | Digi-Key | CP-SJ2-35813A-SMT-CT-ND
36 | HDMI_47659-1100 | J7 | 2086581051 | 1 | 2086581051 | Molex | Digi-Key | 900-2086581051CT-ND
37 | B2B-PH-K-S | J8 | CONN-TH_B2B-PH-K-S | 1 | B2B-PH-K-S | JST Sales America Inc. | Digi-Key | 455-1704-ND
38 | 22uH | L1,L2,L3,L8 | IND-SMD_L6.0-W6.0_ASPI-6045S | 4 | ASPI-6045S-220M-T | Abracon LLC | Digi-Key | 535-ASPI-6045S-220M-TCT-ND
39 | 1u | L4,L5,L6,L7,L9 | L0603 | 5 | MAF1608FAD151CT000 | TDK Corporation | Digi-Key | 445-174936-1-ND
40 | 33uH | L10 | IND-SMD_L6.0-W6.0_ASPI-6045S | 1 | SPM7054VT-330M-D | TDK Corporation | Digi-Key | 445-181516-1-ND
41 | SI2347DS-T1-GE3 | Q1,Q7,Q10,Q19 | SOT-23-3_L2.9-W1.3-P1.83-LS2.4-BR-1 | 4 | SI2347DS-T1-GE3 | Vishay Siliconix | Digi-Key | SI2347DS-T1-GE3CT-ND
42 | DMN67D8LW-13 | Q2,Q3,Q12,Q17 | SOT-323-3_L2.2-W1.3-P1.30-LS2.1-BR | 4 | DMN67D8LW-13 | Diodes Incorporated | Digi-Key | DMN67D8LW-13DICT-ND
43 | IRF5305PBF | Q4 | TO-220F-3_L10.2-W4.7-P2.54-L | 1 | IRF5305PBF | Infineon Technologies | Digi-Key | IRF5305PBF-ND
44 | DMN67D8L-7 | Q5,Q6,Q8,Q9,Q11,Q13,Q14,Q16,Q18,Q20,Q21 | SOT-23-3_L3.0-W1.7-P0.95-LS2.9-BR | 11 | DMN67D8L-7 | Diodes Incorporated | Digi-Key | DMN67D8L-7DICT-ND
45 | DMP2120U-7 | Q15 | SOT-23-3_L2.9-W1.3-P1.90-LS2.4-BR | 1 | DMP2120U-7 | Diodes Incorporated | Digi-Key | DMP2120U-7DICT-ND
46 | 100k | R1,R2,R3,R4,R13,R26,R27,R28,R33,R34,R35,R36,R37,R39,R40,R41,R42,R46,R47,R48,R52 | R0603 | 21 | RC0603FR-07100KL | YAGEO | Digi-Key | 311-100KHRCT-ND
47 | 10k | R5,R9,R10,R11,R12,R14,R15,R32,R38,R43,R44,R51,R53 | R0603 | 13 | RNCP0603FTD10K0 | Stackpole Electronics Inc | Digi-Key | RNCP0603FTD10K0CT-ND
48 | 21k | R6 | R0603 | 1 | ERJ-3EKF2102V | Panasonic Electronic Components | Digi-Key | P21.0KHCT-ND
49 | 2k | R7,R8 | R0603 | 2 | RT0603BRD072KL | YAGEO | Digi-Key | YAG1626CT-ND
50 | 10M | R16 | R0603 | 1 | RC0603FR-0710ML | YAGEO | Digi-Key | 311-10.0MHRCT-ND
51 | 130k | R17,R19 | R0603 | 2 | RT0603BRD07130KL | YAGEO | Digi-Key | YAG1521CT-ND
52 | 20k | R18,R25 | R0603 | 2 | RT0603BRD0720KL | YAGEO | Digi-Key | YAG1582CT-ND
53 | 1M | R20 | R0603 | 1 | AC0603JR-071ML | YAGEO | Digi-Key | 311-1MLECT-ND
54 | 3k | R21 | R0603 | 1 | RT0603BRD073KL | YAGEO | Digi-Key | YAG1657CT-ND
55 | 47k | R22 | R0603 | 1 | RG1608P-473-B-T5 | Susumu | Digi-Key | RG16P47.0KBCT-ND
56 | 16k | R23 | R0603 | 1 | RT0603BRD0716KL | YAGEO | Digi-Key | YAG1546CT-ND
57 | 0 | R24 | R0603 | 1 | RC0603JR-070RL | YAGEO | Digi-Key | 311-0.0GRCT-ND
58 | 0.01 | R45 | R0603 | 1 | CSM0603FT10L0 | Stackpole Electronics Inc | Digi-Key | CSM0603FT10L0CT-ND
59 | 30.1k | R49 | R0603 | 1 | RMCF0603FT30K1 | YAGEO | Digi-Key | RMCF0603FT30K1CT-ND
60 | 9.76k | R50 | R0603 | 1 | RMCF0603FT9K76 | YAGEO | Digi-Key | RMCF0603FT9K76CT-ND
61 | 150 | R58 | R0603 | 1 | RC0603FR-07150RL | YAGEO | Digi-Key | 311-150HRCT-ND
62 | GF-123-0054 | SW1,SW3 | GF-123-0054 | 2 | GF-123-0054 | CW Industries | Digi-Key | CWI333-ND
63 | GF-124-0217 | SW2 | GF-124 | 1 | GF-124-0217 | CW Industries | Digi-Key | CWI434-ND
64 | AP63301WU-7 | U1,U6 | TSOT-23-6_L2.9-W1.6-P0.95-LS2.8-BR | 2 | AP63301WU-7 | Diodes Incorporated | Digi-Key | AP63301WU-7
65 | AP63301WU-7 | U2,U15 | TSOT-23-6_L2.9-W1.6-P0.95-LS2.8-BR | 2 | AP63301WU-7 | DIODES(美台) | Digi-Key | AP63301WU-7
66 | AP7375-33SA-7 | U8 | SOT-23-3_L2.9-W1.3-P1.90-LS2.4-BR | 1 | AP7375-33SA-7 | Diodes Incorporated | Digi-Key | 31-AP7375-33SA-7CT-ND
67 | TLV1811DBVR | U9 | SOT-23-5_L2.9-W1.6-P0.95-LS2.8-BR | 1 | TLV1811DBVR | Texas Instruments | Digi-Key | 296-TLV1811DBVRCT-ND
68 | D-AS321KTR-G1 | U10 | SOT-23-5_L2.9-W1.6-P0.95-LS2.8-BL | 1 | AS321KTR-G1 | Diodes Incorporated | Digi-Key | AS321KTR-G1DICT-ND
69 | AP331AWG-7 | U11,U12,U14 | SOT-25-5_L3.0-W1.8-P0.95-LS3.0-BR | 3 | AP331AWG-7 | Diodes Incorporated | Digi-Key | AP331AWGDICT-ND
70 | LM2596T-ADJ/NOPB | U13 | TO-220-5_L10.5-W15.5-P1.70-TL | 1 | LM2596T-ADJ/NOPB | Texas Instruments | Digi-Key | LM2596T-ADJ/NOPB-ND
71 | NCS214RSQT2G | U16 | SC-70-6_L2.0-W1.3-P0.65-LS2.1-BL | 1 | NCS214RSQT2G | onsemi | Digi-Key | NCS214RSQT2GOSCT-ND
72 | 1903815-1 | USB1,USB2 | USB-A-TH_1903815-1 | 2 | 1903815-1 | TE Connectivity AMP Connectors | Digi-Key | A107353-ND
73 | TL061IDT | U3 | SOIC-8_L4.9-W3.9-P1.27-LS6.2-BL | 1 | TL061IDT | STMicroelectronics | Digi-Key | 497-4054-1-ND

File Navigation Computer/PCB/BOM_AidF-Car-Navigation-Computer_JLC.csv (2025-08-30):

ID | Name | Designator | Footprint | Quantity | Manufacturer Part | Manufacturer | Supplier | Supplier Part | Price
1 | DF40C-100DS-0.4V(51) | CN1,CN2 | CONN-SMD_100P-P0.40_X0408FVS-100F-LPV01 | 2 | DF40C-100DS-0.4V(51) | Hirose Electric Co Ltd | Digi-Key | H11615CT-ND

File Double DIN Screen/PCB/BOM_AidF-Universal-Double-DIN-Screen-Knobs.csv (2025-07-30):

ID | Name | Designator | Footprint | Quantity | Manufacturer Part | Manufacturer | Supplier | Supplier Part | Price
1 | 150 | R8,R9,R10,R1,R2,R3,R4,R5,R6 | R0603 | 9 | RC0603FR-07150RL | YAGEO | Digi-Key | 311-150HRCT-ND
2 | 100 | R7 | R0805 | 1 | CRGH0805F100R | TE Connectivity Passive Product | Digi-Key | A126416CT-ND
3 | 20021321-00030T4LF | J1 | 1.27 2X15 20021311-00030T4LF | 1 | 20021111-00030T4LF | Amphenol ICC (FCI) | Digi-Key | 609-3721-ND
4 | QBLP601-IW | LED2,D7,D8,D1,D2,D3,D4,D5,D6 | LED0603-RD | 9 | QBLP601-IW | QT Brightek (QTB) | Digi-Key | 1516-1057-1-ND
5 | TL1015AF160QG | SW1,SW2,SW3,SW4,SW5,SW6 | KEY-SMD_6P-L3.9-W2.9-LS4.5 | 6 | TL1015AF160QG | E-Switch | Digi-Key | EG4344CT-ND
6 | RKJXT1F42001 | S2 | SW-TH_RKJXT1F42001 | 1 | RKJXT1F42001 | Alps Alpine | Digi-Key | 4809-RKJXT1F42001-ND
7 | PEC11S-9213K-S0015 | S1 | RES-ADJ-SMD_PEC11S-9213K-S0015 | 1 | PEC11S-9213K-S0015 | Bourns Inc. | Digi-Key | PEC11S-9213K-S0015-ND
8 | CLM3C-MKW-CWAXB233 | LED1 | LED-SMD_L2.7-W2.0-LS3.0-FD_CLM3C-WKW-CWBYA453 | 1 | CLM3C-MKW-CWAXB233 | Cree LED | Digi-Key | CLM3C-MKW-CWAXB233CT-ND

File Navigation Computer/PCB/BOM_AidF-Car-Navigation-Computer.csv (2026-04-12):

ID | Name | Designator | Footprint | Quantity | Manufacturer Part | Manufacturer | Supplier | Supplier Part | Price
1 | USB4105-GF-A | USB1 | TYPE-C-SMD_SBC-160S1A-20-S412 | 1 | USB4105-GF-A | GCT | Digi-Key | 2073-USB4105-GF-ACT-ND
2 | 0.1uF | C17,C20,C41,C43,C47,C48,C50,C71,C74,C75,C28,C73,C72,C55,C52,C46,C45,C42,C34,C33,C19,C18,C14,C13,C12,C10,C8,C7,C4,C3,C15,C64,C61,C58,C16,C69,C70,C76,C21,C22 | C0603 | 40 | 0603B104K101CT | Walsin Technology Corporation | Digi-Key | 1292-1392-1-ND
3 | 1nF | C27 | C0603 | 1 | GRM1885C1H102JA01D | Murata Electronics | Digi-Key | 490-1451-1-ND
4 | 18pF | C51,C68 | C0603 | 2 | 712-QSCP251Q180J1GV001TDKR-ND | Johanson Technology Inc. | Digi-Key | 712-QSCP251Q180J1GV001TCT-ND
5 | 27 | R6,R32,R34,R39,R40,R51,R49,R50,R47,R48 | R0603 | 10 | RC0603FR-0727RL | YAGEO | Digi-Key | 311-27.0HRCT-ND
6 | 100k | R19,R23,R52,R27,R28,R22,R63,R64,R65 | R0603 | 9 | RC0603FR-07100KL | YAGEO | Digi-Key | 311-100KHRCT-ND
7 | 1.5k | R53 | R0603 | 1 | RC0603JR-071K5L | YAGEO | Digi-Key | 311-1.5KGRCT-ND
8 | 10k | R55,R10,R1,R2,R3,R8,R9,R11,R12,R16,R17,R18,R31,R41,R44,R45,R46,R69,R70,R72,R73,R74,R77,R78,R79,R59,R61,R20 | R0603 | 28 | RNCP0603FTD10K0 | Stackpole Electronics Inc | Digi-Key | RNCP0603FTD10K0CT-ND
9 | USB2514B-AEZC | U9 | TQFN-36_L6.0-W6.0-P0.50-BL-EP3.7 | 1 | USB2514B-AEZC | Microchip Technology | Digi-Key | 638-1122-ND
10 | 2N7002 | Q4 | SOT-23_L2.9-W1.3-P0.95-LS2.4-BR | 1 | DMN3404L-7 | Diodes Incorporated | Digi-Key | DMN3404LDICT-ND
11 | DMN67D8LW-13 | Q6,Q22,Q23 | SOT-23_L2.9-W1.3-P0.95-LS2.4-BR | 3 | DMN67D8LW-13 | Diodes Incorporated | Digi-Key | DMN67D8LW-13DICT-ND
12 | MCP2561 | U3 | SOIC-8_L4.9-W3.9-P1.27-LS6.0-BL-2 | 1 | MCP2561T-E/SN | Microchip Technology | Digi-Key | MCP2561T-E/SNCT-ND
13 | MCP2562 | U5 | SOIC-8_L4.9-W3.9-P1.27-LS6.0-BL-2 | 1 | MCP2562-E/SN | Microchip Technology | Digi-Key | MCP2562-E/SN-ND
14 | 1uF | C44,C49,C54,C53,C38,C37,C77 | C0603 | 7 | CC0603KRX5R8BB105 | YAGEO | Digi-Key | 311-1445-1-ND
15 | PROG | D8 | LED0805-RD | 1 | LTST-C171KGKT | Lite-On Inc. | Digi-Key | 160-1426-1-ND
16 | 150 | R35,R57,R58 | R0603 | 3 | RC0603FR-07150RL | YAGEO | Digi-Key | 311-150HRCT-ND
17 | 1k | R36 | R0603 | 1 | RC0603FR-071KL | YAGEO | Digi-Key | 311-1.00KHRCT-ND
18 | 5.1k | R37,R38 | R0603 | 2 | RC0603FR-075K1L | YAGEO | Digi-Key | 311-5.10KHRCT-ND
19 | OS102011MS2QN1 | SW1 | SW-TH_OS102011MS2QN1 | 1 | OS102011MS2QN1 | C&K | Digi-Key | CKN9565-ND
20 | 74LVC1G332GW,125 | U4 | SOT-363_L2.0-W1.3-P0.65-LS2.1-BL | 1 | 74LVC1G332GW,125 | Nexperia USA Inc. | Digi-Key | 1727-6979-1-ND
21 | 12.288MHZ | U7 | OSC-SMD_4P-L2.5-W2.0-BL-1 | 1 | KC2520Z12.2880C1KX00 | KYOCERA AVX | Digi-Key | 478-KC2520Z12.2880C1KX00CT-ND
22 | FSUSB42MUX | U11,U14 | MSOP-10_L3.0-W3.0-P0.50-LS5.0-BL | 2 | FSUSB42MUX | onsemi | Digi-Key | FSUSB42MUXCT-ND
23 | 24MHz | X3 | CRYSTAL-SMD_4P-L2.0-W1.6-BL-B | 1 | XRCGB24M000F3M00R0 | Murata Electronics | Digi-Key | 490-5576-1-ND
24 | 1u | L6,L9,L8,L5,L4,L3,L2,L1,L10 | L0603 | 9 | MAF1608FAD151CT000 | TDK Corporation | Digi-Key | 445-174936-1-ND
25 | 100u | C5,C1,C2,C6,C9,C11 | CAP-D6.3×F2.5 | 6 | ESK107M025AE3EA | KEMET | Digi-Key | 399-6650-1-ND
26 | DMN67D8LW-13 | Q8,Q16,Q19 | SOT-323-3_L2.2-W1.3-P1.30-LS2.1-BR | 3 | DMN67D8LW-13 | Diodes Incorporated | Digi-Key | DMN67D8LW-13DICT-ND
27 | DF40C-100DS-0.4V(51) | CN1,CN2 | CONN-SMD_100P-P0.40_X0408FVS-100F-LPV01 | 2 | DF40C-100DS-0.4V(51) | Hirose Electric Co Ltd | Digi-Key | H11615CT-ND
28 | 5.6V | D1,D5 | SOD-123_L2.7-W1.6-LS3.7-RD-A | 2 | MMSZ5232BT1G | onsemi | Digi-Key | MMSZ5232BT1GOSCT-ND
29 | 3.6V | D2 | SOD-123_L2.7-W1.6-LS3.7-RD-A | 1 | MMSZ4685-TP | Micro Commercial Co | Digi-Key | MMSZ4685-TPMSCT-ND
30 | 6.8V | D3,D4 | SOD-123_L2.7-W1.6-LS3.7-RD-A | 2 | MMSZ4692T1G | onsemi | Digi-Key | MMSZ4692T1GOSCT-ND
31 | SD103AWS-TP | D6,D7,D13,D16,D9 | SOD-323_L1.8-W1.3-LS2.6-FD | 5 | SD103AWS-TP | Micro Commercial Co | Digi-Key | SD103AWSTPMSCT-ND
32 | ACTIVITY | D14 | LED-TH_BD5.0-P2.54-FD | 1 | LTL-4233 | Lite-On Inc. | Digi-Key | 160-1130-ND
33 | POWER | D15 | LED-TH_BD5.0-P2.54-FD | 1 | LTL-4273 | Lite-On Inc. | Digi-Key | 160-1966-ND
34 | PPTC032LFBN-RC | J3 | RHDR6W75P254_2X3_812X508X850P | 1 | PPTC032LFBN-RC | Sullins Connector Solutions | Digi-Key | S7071-ND
35 | HDR-M-2.54_2x3 | J6 | HDR-M-2.54_2X3 | 1 | M20-9980346 | Harwin Inc. | Digi-Key | 952-2121-ND
36 | SI2347DS-T1-GE3 | Q1,Q2,Q3,Q5,Q7,Q17 | SOT-23-3_L2.9-W1.3-P1.83-LS2.4-BR-1 | 6 | SI2347DS-T1-GE3 | Vishay Siliconix | Digi-Key | SI2347DS-T1-GE3CT-ND
37 | 470 | R4,R5,R54,R81 | R0603 | 4 | RC0603JR-07470RL | YAGEO | Digi-Key | 311-470GRCT-ND
38 | 100 | R7 | R0603 | 1 | ERJ-3EKF1000V | Panasonic Electronic Components | Digi-Key | P100HCT-ND
39 | MEM2061-01-188-00-A (SPI) | SD1 | MEM2061-01-188-00-A | 1 | MEM2061-01-188-00-A | GCT | Digi-Key | 2073-MEM2061-01-188-00-ACT-ND
40 | ATMEGA3208-AU | U1 | TQFP-32_L7.0-W7.0-P0.80-LS9.0-BL | 1 | ATMEGA3208-AU | Microchip Technology | Digi-Key | ATMEGA3208-AFRCT-ND
41 | PCM5101APWR | U13 | TSSOP-20_L6.5-W4.4-P0.65-LS6.5-BL | 1 | PCM5101APWR | Texas Instruments | Digi-Key | 296-36706-1-ND
42 | PCM1808PWR | U21 | TSSOP-14_L5.0-W4.4-P0.65-LS6.4-BL | 1 | PCM1808PWR | Texas Instruments | Digi-Key | 296-26307-1-ND
43 | SN74LVC2G14DCKR | U22 | SC-70-6_L2.0-W1.3-P0.65-LS2.2-BL | 1 | SN74LVC2G14DCKR | Texas Instruments | Digi-Key | 296-13011-1-ND
44 | LM2904BAQDRQ1 | U17 | SOIC-8_L4.9-W3.9-P1.27-LS6.0-BL | 1 | LM2904BIDR | Texas Instruments | Digi-Key | 296-LM2904BIDRCT-ND
45 | 20k | R43,R42,R60,R62 | R0603 | 4 | ERJ-3EKF2002V | Panasonic Electronic Components | Digi-Key | P20.0KHCT-ND
46 | 2.2uF | C36,C35 | C0603 | 2 | GRM188R61E225KA12D | Murata Electronics | Digi-Key | 490-10731-1-ND
47 | SN74LVC2G04DBVR_C19829671 | U2 | SOT-23-6_L2.9-W1.6-P0.95-LS2.8-BR | 1 | SN74LVC2G04DBVR | Texas Instruments | Digi-Key | 296-13261-1-ND
48 | FH12-20S-0.5SH(55) | FPC1 | FPC-SMD_FH12-20S-0.5SH-55 | 1 | FH12-20S-0.5SH(55) | Hirose Electric Co Ltd | Digi-Key | HFJ120CT-ND
49 | 12k | R30 | R0603 | 1 | RMCF0603FT12K0 | Stackpole Electronics Inc | Digi-Key | RMCF0603FT12K0CT-ND
50 | MFI337S3959 | U6 | USON-8_L2.5-W2.5-P0.50-BL-EP | 1 | MFI337S3959 | null | LCSC | C2837233
51 | HDR-M-2.54_1x8 | J7,J2 | HDR-M-2.54_1X8 | 2 | PH1-08-UA | Adam Tech | Digi-Key | 2057-PH1-08-UA-ND
52 | HDR-M-2.54_1x2 | J5 | HDR-M-2.54_1X2 | 1 | PH1-02-UA | Adam Tech | Digi-Key | 2057-PH1-02-UA-ND
53 | HDR-M-2.54_1x10 | J4,J1 | HDR-M-2.54_1X10 | 2 | PH1-10-UA | Adam Tech | Digi-Key | 2057-PH1-10-UA-ND
54 | 10uF | C60,C63,C65,C66,C67 | C0805 | 5 | CL21A106KAYNNNE | Samsung Electro-Mechanics | Digi-Key | 1276-2891-1-ND
55 | MCP4251T-103E/SL | U24 | SOIC-14_L8.7-W3.9-P1.27-LS6.0-BL | 1 | MCP4251T-103E/SL | Microchip Technology | Digi-Key | MCP4251T-103E/SLCT-ND
56 | MCP6006T-E/OT | U26 | SOT-23-5_L2.9-W1.6-P0.95-LS2.8-BR | 1 | MCP6006T-E/OT | Microchip Technology | Digi-Key | MCP6006T-E/OT
57 | TL062VD | U25 | SO-8_L4.9-W3.9-P1.27-LS6.0-BL | 1 | TL062CDR | Texas Instruments | Digi-Key | 296-1281-1-ND
58 | 330p | C62,C59 | C0603 | 2 | KGM15ACG1H331FT | KYOCERA AVX | Digi-Key | 478-KGM15ACG1H331FTCT-ND
59 | FT231XS-R | U10 | SSOP-20_L8.6-W3.9-P0.64-LS6.0-BL | 1 | FT231XS-R | FTDI, Future Technology Devices International Ltd | Digi-Key | 768-1129-1-ND
60 | RT9742GGJ5 | U8 | TSOT-23-5_L2.9-W1.6-P0.95-LS2.8-BR | 1 | RT9742GGJ5 | Richtek USA Inc. | Digi-Key | 1028-1436-1-ND

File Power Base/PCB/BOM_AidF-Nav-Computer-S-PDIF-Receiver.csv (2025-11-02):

ID | Name | Designator | Footprint | Quantity | Manufacturer Part | Manufacturer | Supplier | Supplier Part | Price
1 | 0.1uF | C3,C4,C5 | C0603 | 3 | 0603B104K101CT | Walsin Technology Corporation | Digi-Key | 1292-1392-1-ND
2 | 4.7nF | C17 | C0603 | 1 | CGA3E2C0G1H472J080AA | TDK Corporation | Digi-Key | 445-6912-1-ND
3 | 68nF | C18 | C0603 | 1 | KGM15AR71C683KT | KYOCERA AVX | Digi-Key | 478-KGM15AR71C683KTCT-ND
4 | 1uF | C40 | C0603 | 1 | CC0603KRX5R8BB105 | YAGEO | Digi-Key | 311-1445-1-ND
5 | PH1RA-04-UA | CN1,CN2 | MALE HEADER 1X4 | 2 | PH1RA-04-UA | Adam Tech | Digi-Key | 2057-PH1RA-04-UA-ND
6 | PH1RA-02-UA | CN3 | HDR-TH_PH1RA-02-UA | 1 | PH1RA-02-UA | Adam Tech | Digi-Key | 2057-PH1RA-02-UA-ND
7 | 10k | R24 | R0603 | 1 | RNCP0603FTD10K0 | Stackpole Electronics Inc | Digi-Key | RNCP0603FTD10K0CT-ND
8 | 680 | R29 | R0603 | 1 | RMCF0603FT680R | Stackpole Electronics Inc | Digi-Key | RMCF0603FT680RCT-ND
9 | 100 | R30 | R0603 | 1 | ERJ-3EKF1000V | Panasonic Electronic Components | Digi-Key | P100HCT-ND
10 | TLV3501AIDBVRG4 | U4 | SOT-23-6_L2.9-W1.6-P0.95-LS2.8-BR | 1 | TLV3501AIDBVRG4 | Texas Instruments | Digi-Key | 296-35977-1-ND
11 | DIR9001PWR | U5 | TSSOP-28_L9.7-W4.4-P0.65-LS6.4-BL | 1 | DIR9001PWR | Texas Instruments | Digi-Key | 296-38926-1-ND
12 | 24.576MHz | X1 | CRYSTAL-SMD_4P-L3.2-W2.5-BL | 1 | ABM8G-24.576MHZ-4Y-T3 | Abracon LLC | Digi-Key | 535-10914-1-ND

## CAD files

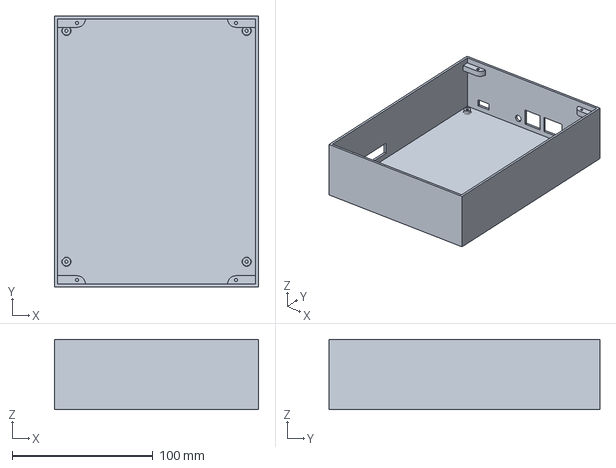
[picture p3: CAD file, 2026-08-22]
Full Pi Power Base/CAD/Full Pi Power Base-Full Pi Power Base.3mf
145.0 x 192.5 x 50.0 mm

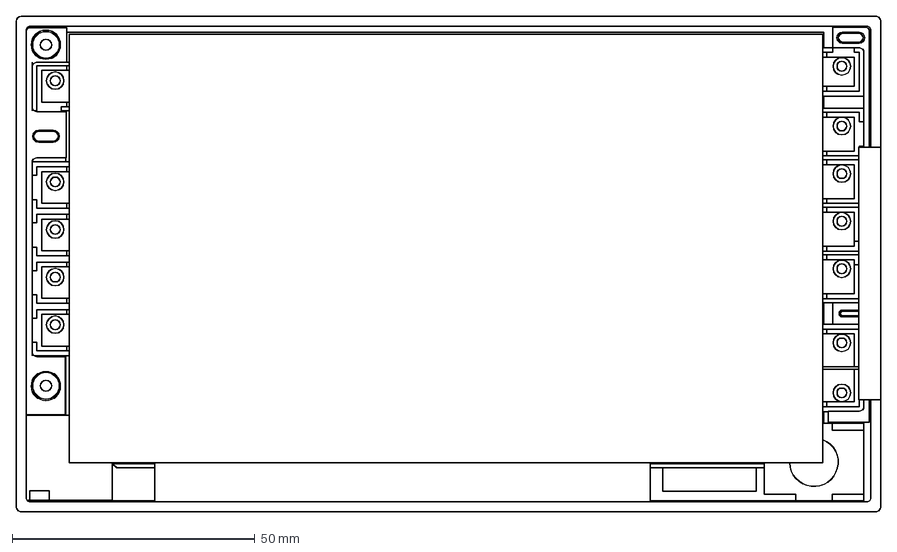
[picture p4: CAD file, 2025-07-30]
Double DIN Screen/CAD/Double DIN Screen Motorized 6 Inch-Main.dxf
178.0 x 102.0 mm

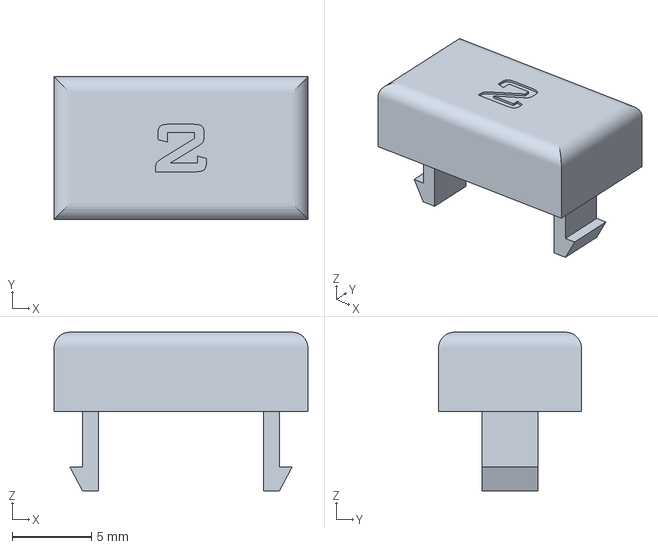
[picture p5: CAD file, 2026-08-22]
Double DIN Screen/CAD/Double DIN Screen Motorized 6 Inch-Preset Button 2.3mf
16.0 x 9.00 x 10.0 mm

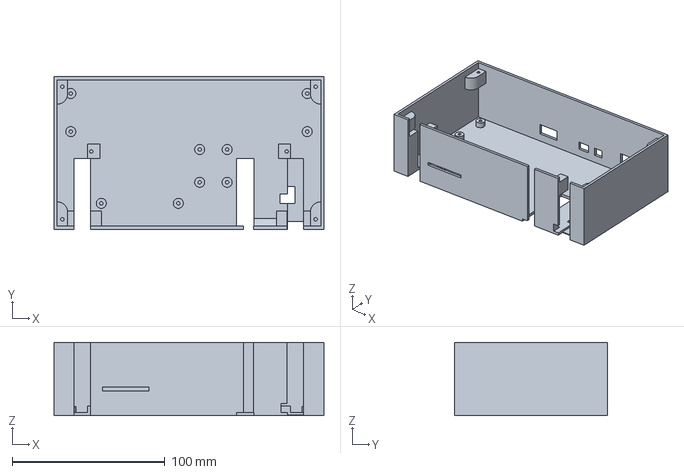
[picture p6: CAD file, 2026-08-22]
Double DIN Screen/CAD/Print Files/Test Print Enclosure.3mf
177.0 x 100.0 x 48.0 mm

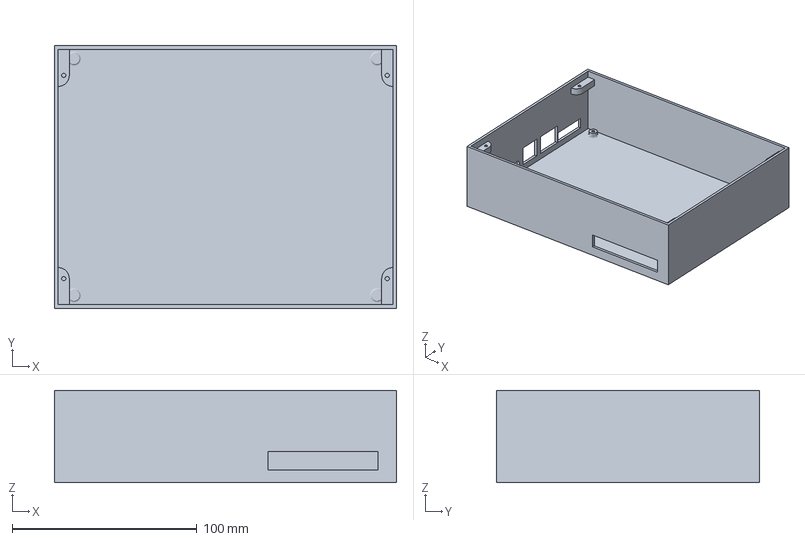
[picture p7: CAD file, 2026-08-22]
Full Pi Power Base/CAD/Print Files/Base Bottom Test.3mf
185.0 x 142.0 x 50.0 mm

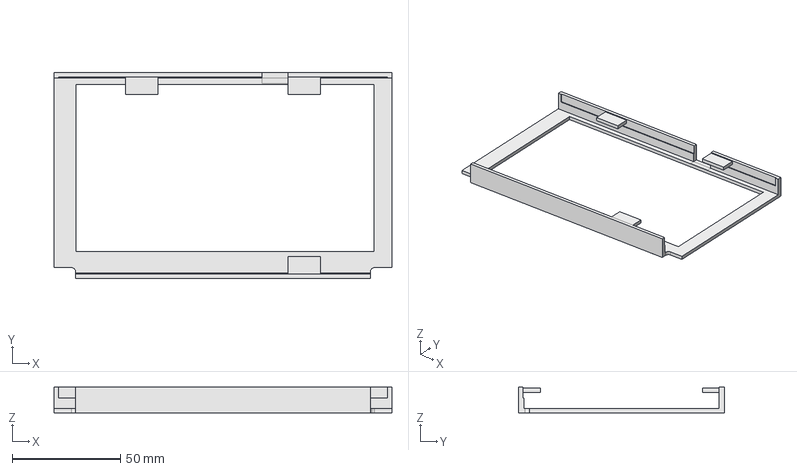
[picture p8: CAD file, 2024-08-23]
Vehicle-Specific/Honda GA-Net II/2006-2011 Navigation Screen/Enclosure/8th Gen AIBT Front.FCStd
156.0 x 95.0 x 12.0 mm

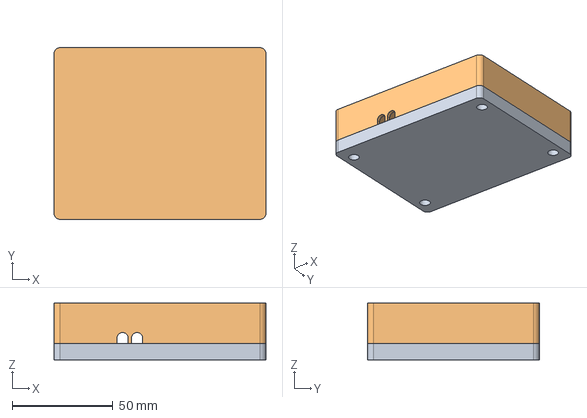
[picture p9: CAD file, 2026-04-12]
Vehicle-Specific/Honda GA-Net II/Audio Source Translator/CAD/GA-Net Translator Enclosure.FCStd
105.0 x 85.0 x 28.0 mm
GA-Net Translator Lower
GA-Net Translator Upper

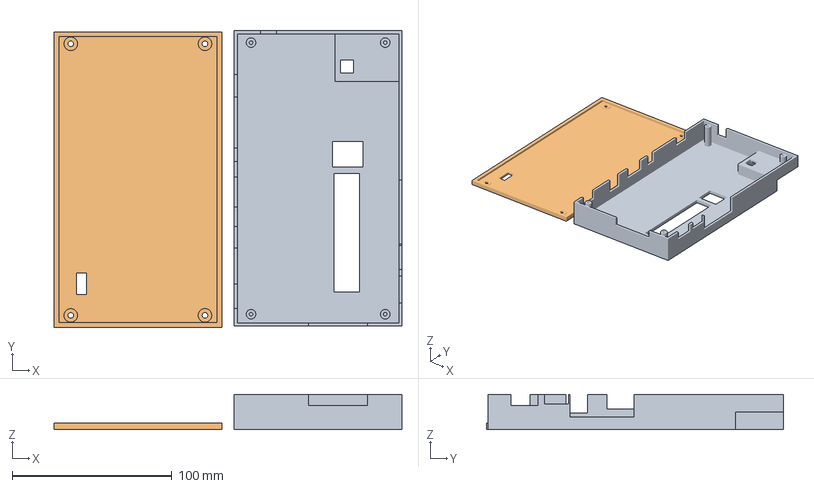
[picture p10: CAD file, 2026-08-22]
Vehicle-Specific/Honda GA-Net II/CAN Bus Translator/CAD/CANslator Enclosure Print.3mf
217.8 x 185.7 x 22.0 mm
CANslator Enclosure-CANslator Enclosure Top
CANslator Enclosure-CANslator Enclsoure Bottom

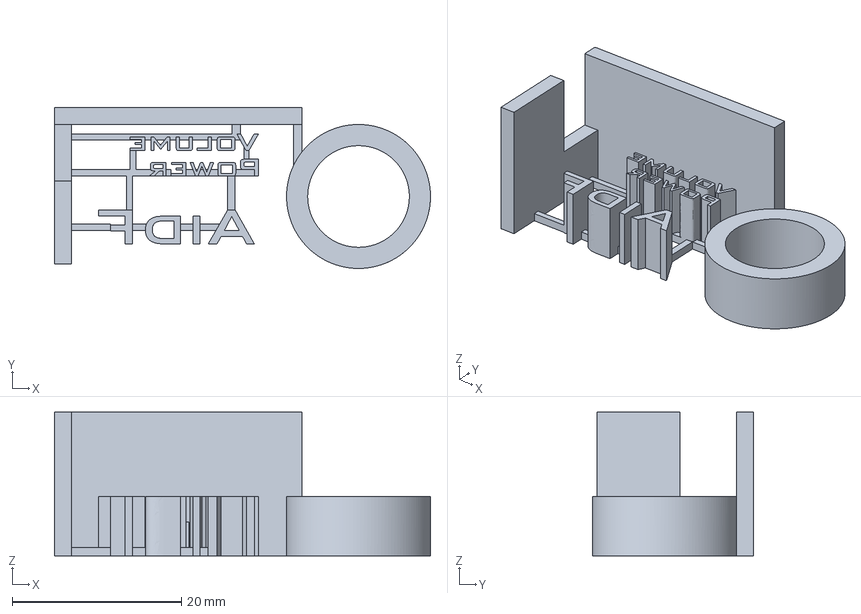
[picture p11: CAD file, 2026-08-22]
Double DIN Screen/CAD/Print Files/Screen Panel Stencil.3mf
44.4 x 19.0 x 17.0 mm

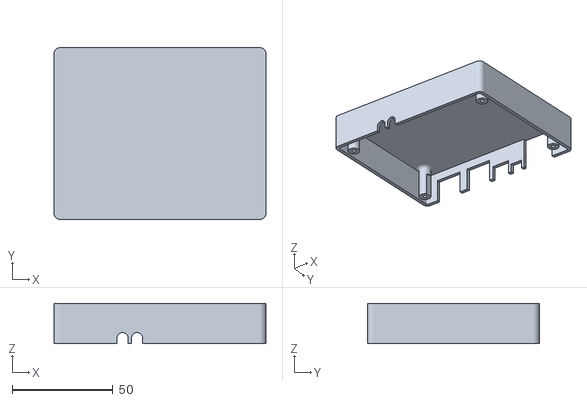
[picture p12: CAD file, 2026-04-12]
Vehicle-Specific/Honda GA-Net II/Audio Source Translator/CAD/GA-Net Translator Enclosure-GA-Net Translator Upper.stl
105.0 x 85.0 x 20.0

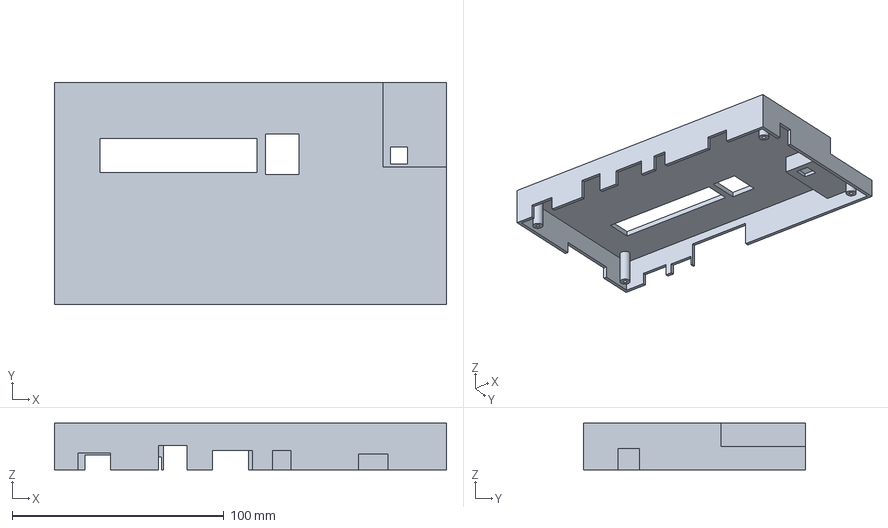
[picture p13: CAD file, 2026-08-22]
Vehicle-Specific/Honda GA-Net II/CAN Bus Translator/CAD/CANslator Enclosure-CANslator Enclosure Top.3mf
185.0 x 105.0 x 22.0 mm

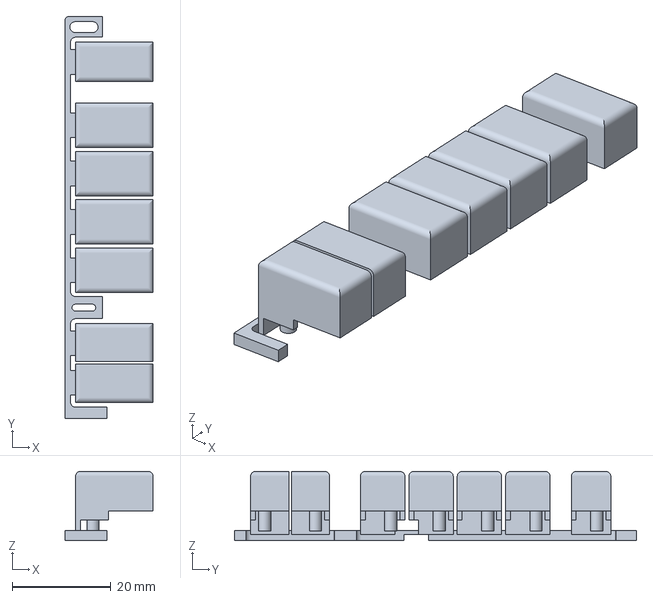
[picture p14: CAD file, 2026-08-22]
Double DIN Screen/CAD/Double DIN Screen Motorized 6 Inch-Left Buttons.3mf
17.8 x 81.4 x 14.0 mm

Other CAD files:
Full Pi Power Base/CAD/Full Pi Power Base.FCStd
Double DIN Screen/CAD/JLC Print Files/Screen Buttons Preset 2.3mf
Single DIN Radio-Nav Enclosure/Radio Nav Enclosure.FCStd
Double DIN Screen/CAD/Double DIN Screen Motorized 6 Inch-Preset Button 4.3mf
Double DIN Screen/CAD/JLC Print Files/Screen Buttons Preset 3.3mf
Double DIN Screen/CAD/JLC Print Files/Screen Buttons Left.3mf
Double DIN Screen/CAD/141_TS0101F020P.stp
Double DIN Screen/CAD/Double DIN Screen Motorized 6 Inch-Knob.dxf
Double DIN Screen/CAD/Double DIN Screen Motorized 6 Inch-Left Screen Guide.3mf
Double DIN Screen/CAD/Double DIN Screen Motorized 6 Inch-Nav Toggle Cover.3mf
Double DIN Screen/CAD/Double DIN Screen Motorized 6 Inch-Preset Button 1.3mf
Double DIN Screen/CAD/Double DIN Screen Motorized 6 Inch-Preset Button 3.3mf
Double DIN Screen/CAD/Double DIN Screen Motorized 6 Inch-Preset Button 5.3mf
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

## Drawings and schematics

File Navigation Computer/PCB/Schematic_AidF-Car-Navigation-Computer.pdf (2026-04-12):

# LEDs /LED_ACTIVITY_GATE /LED_POWER_GATE

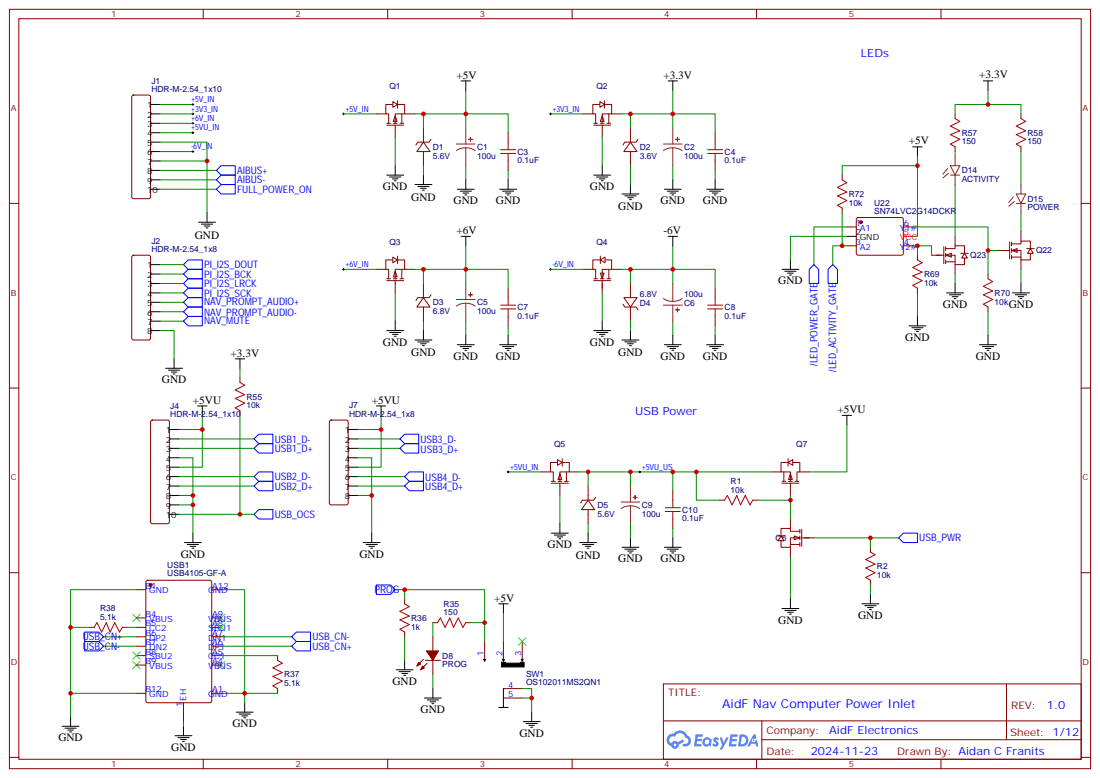
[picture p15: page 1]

Drawn By: Aidan C Franits

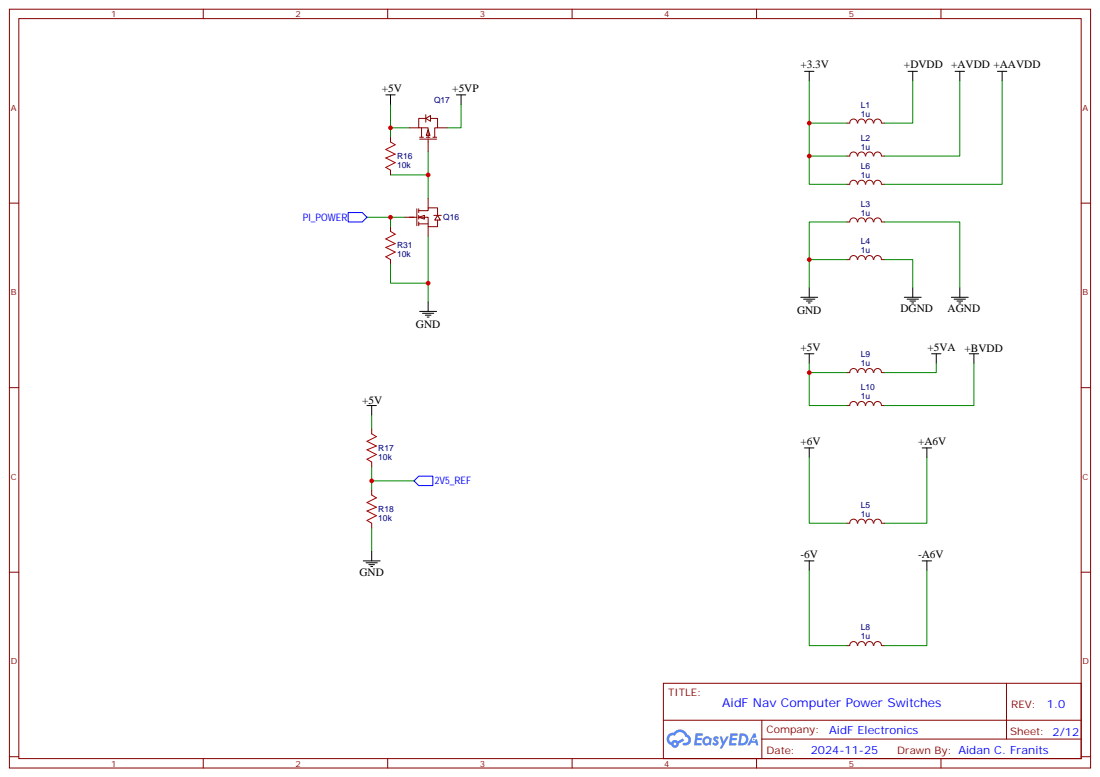
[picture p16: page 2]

Drawn By: Aidan C. Franits

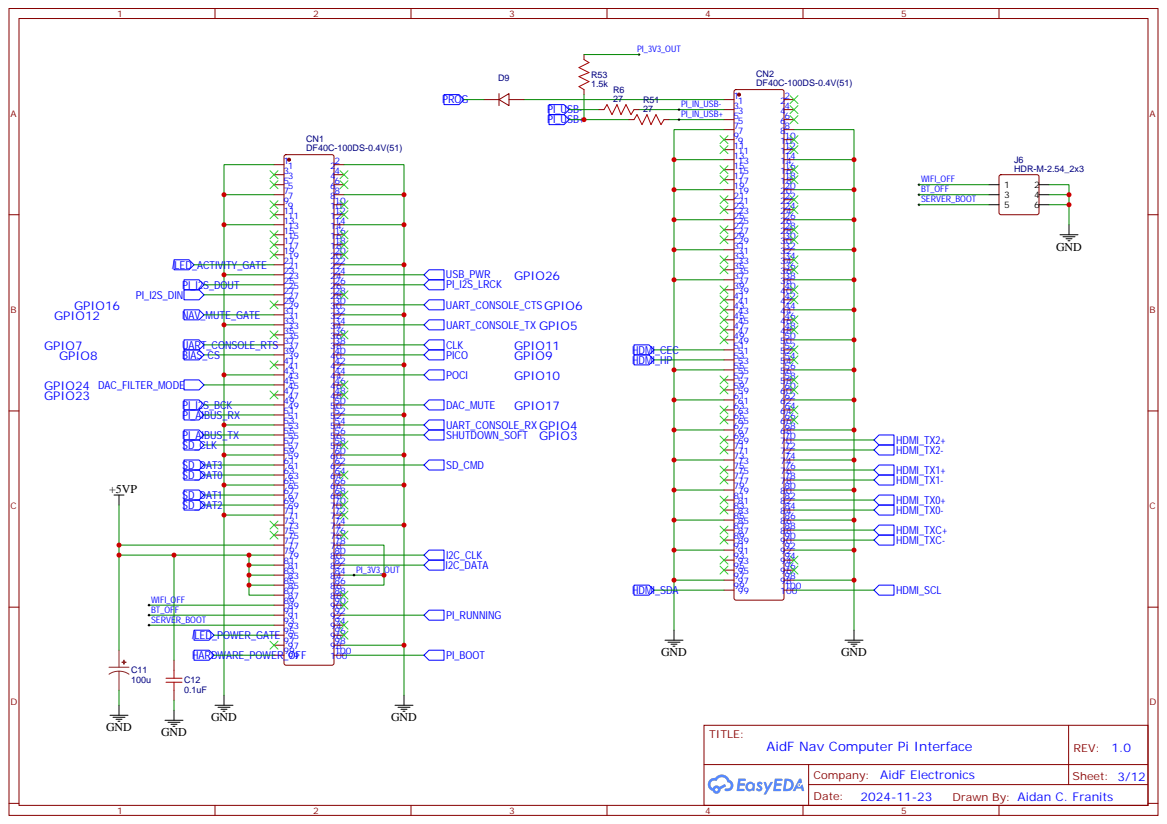
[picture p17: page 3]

Drawn By: Aidan C. Franits

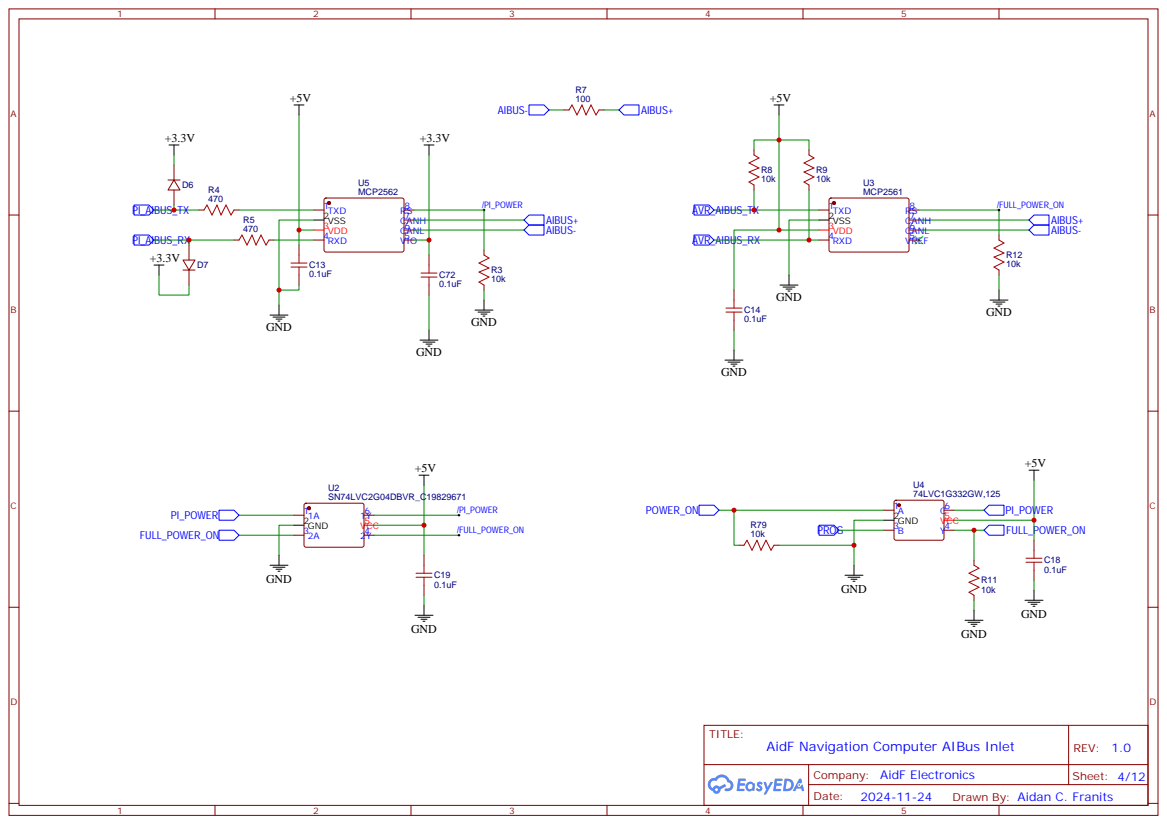
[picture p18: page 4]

Drawn By: Aidan C. Franits

## DAC

## DAC_MUTE

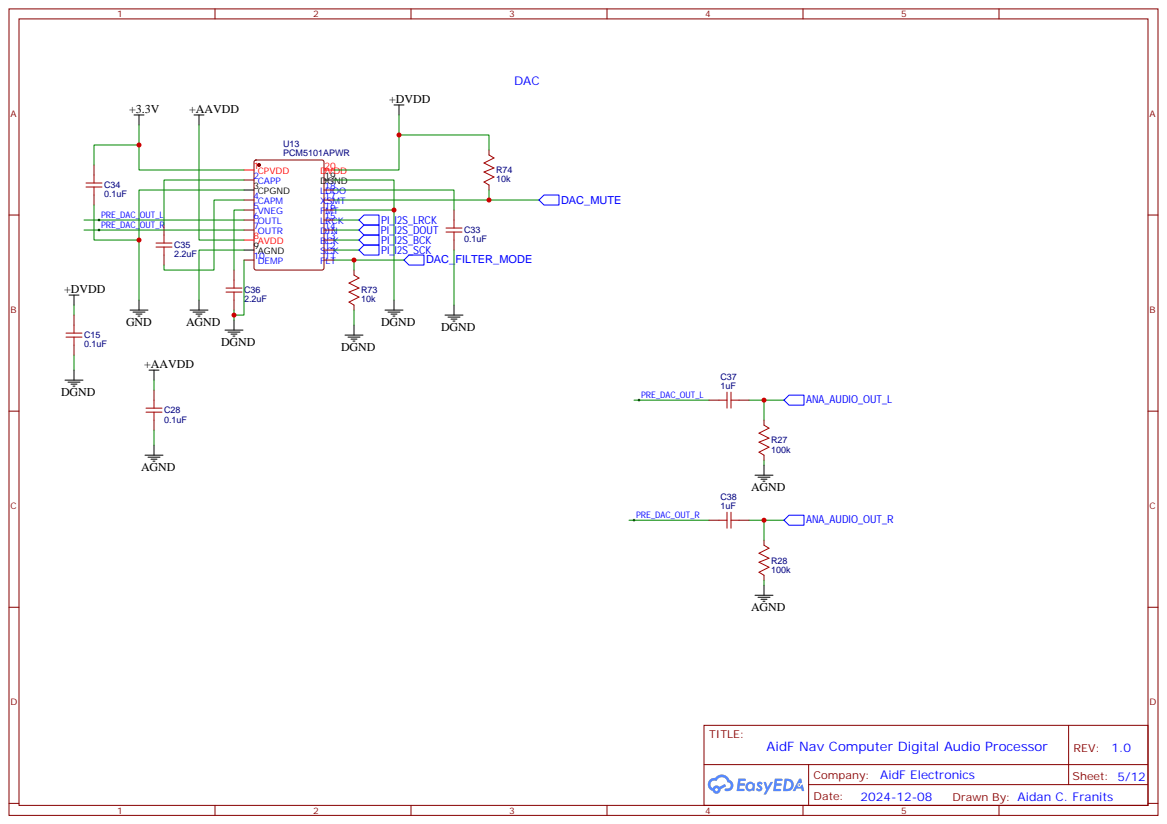
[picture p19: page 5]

Drawn By: Aidan C. Franits

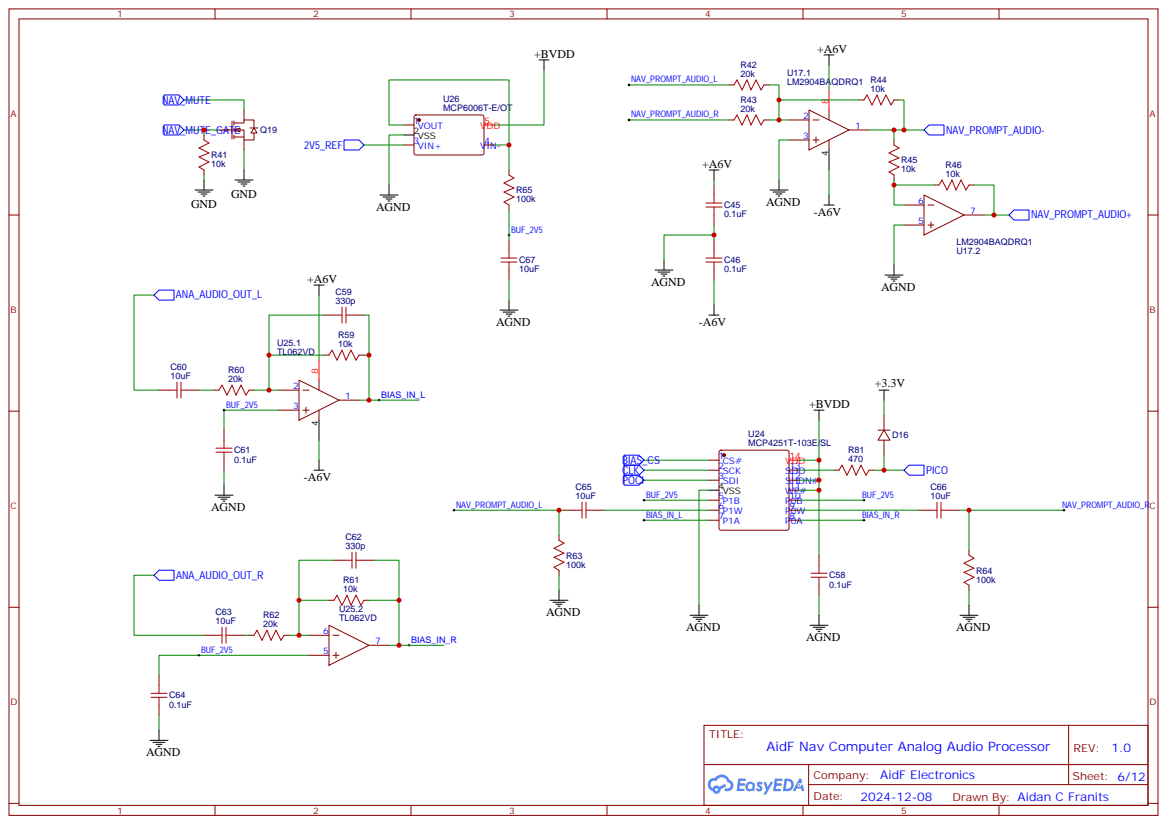
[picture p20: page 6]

P0B10 WP# 11 SHDN# 12 SDO 13 VDD 14

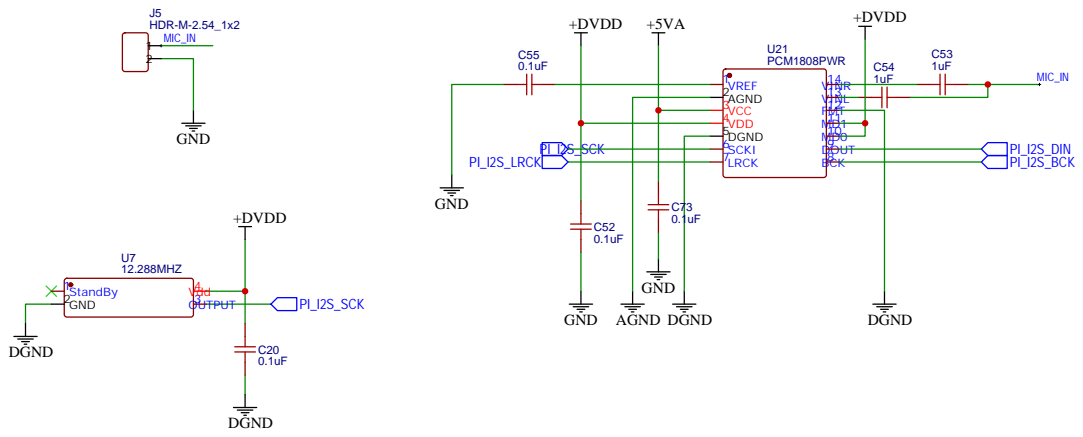
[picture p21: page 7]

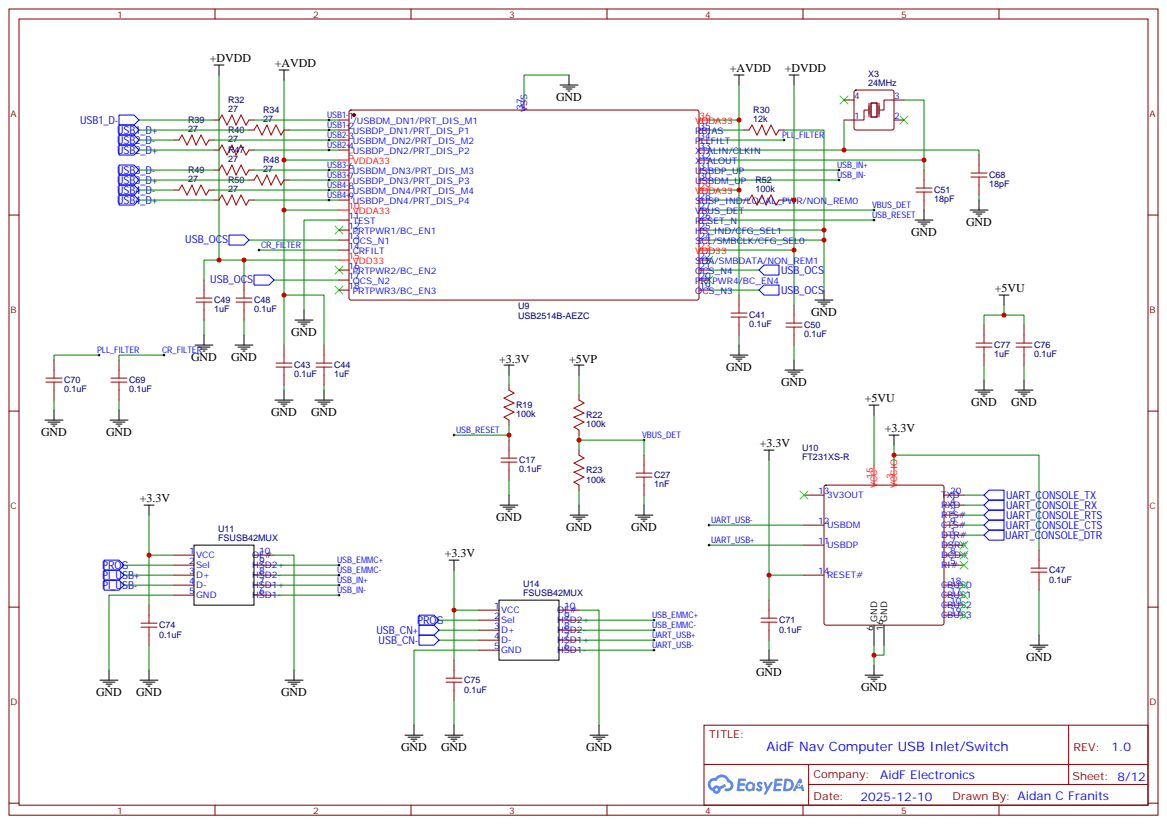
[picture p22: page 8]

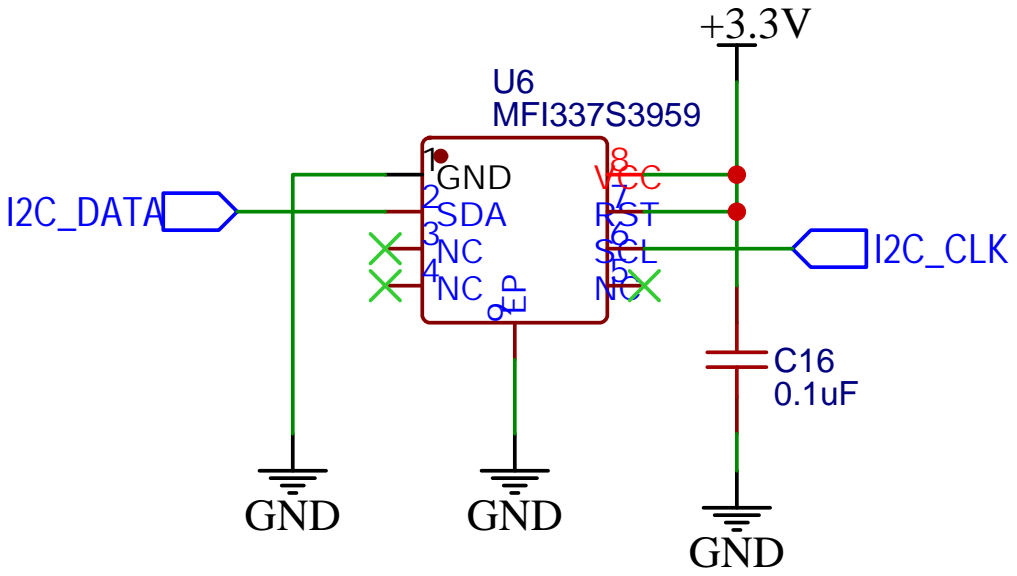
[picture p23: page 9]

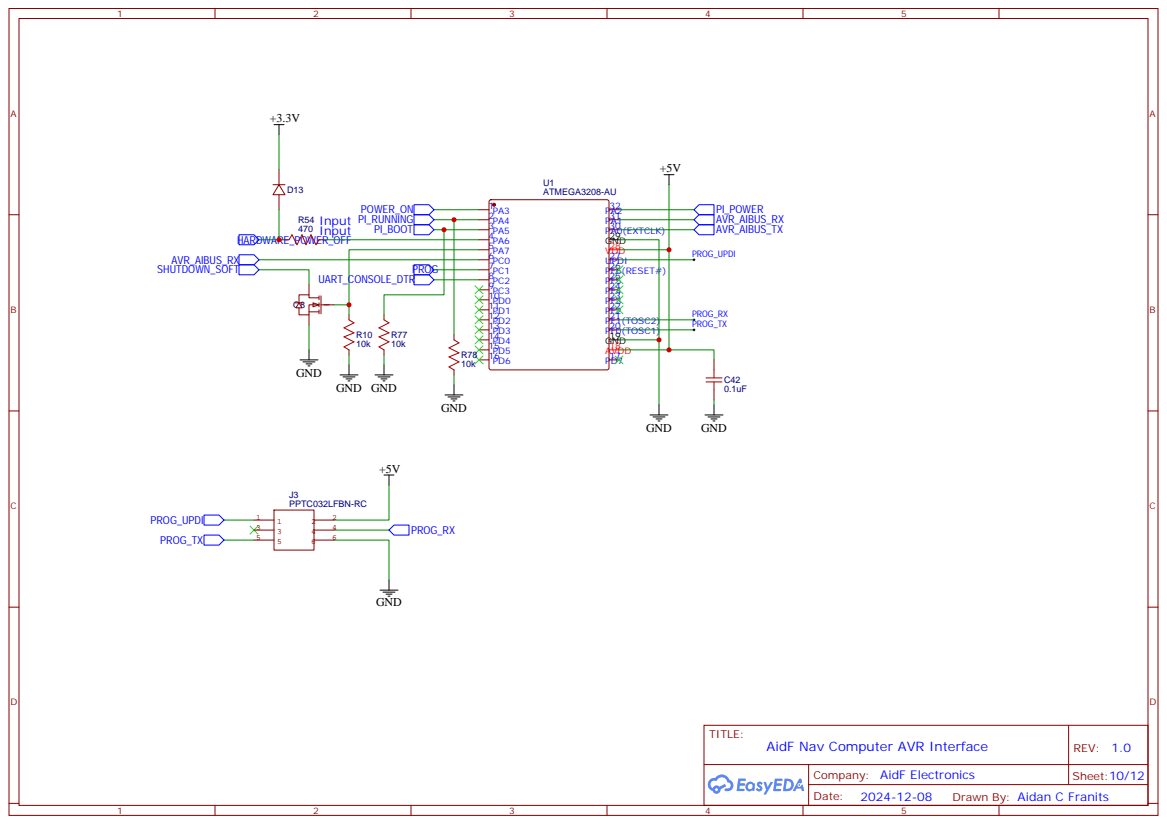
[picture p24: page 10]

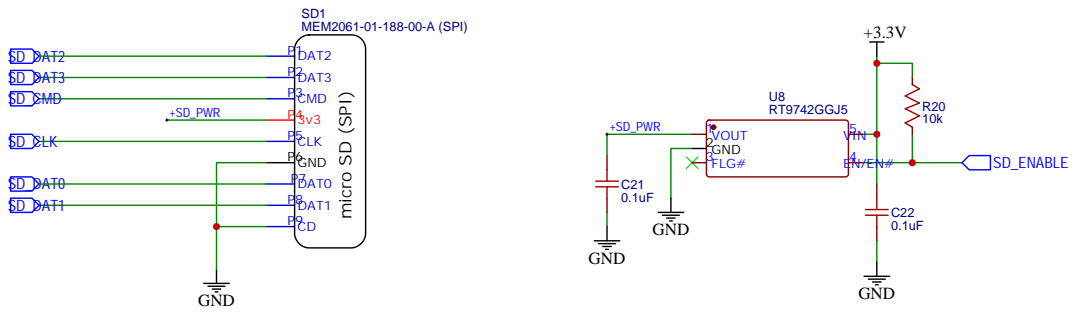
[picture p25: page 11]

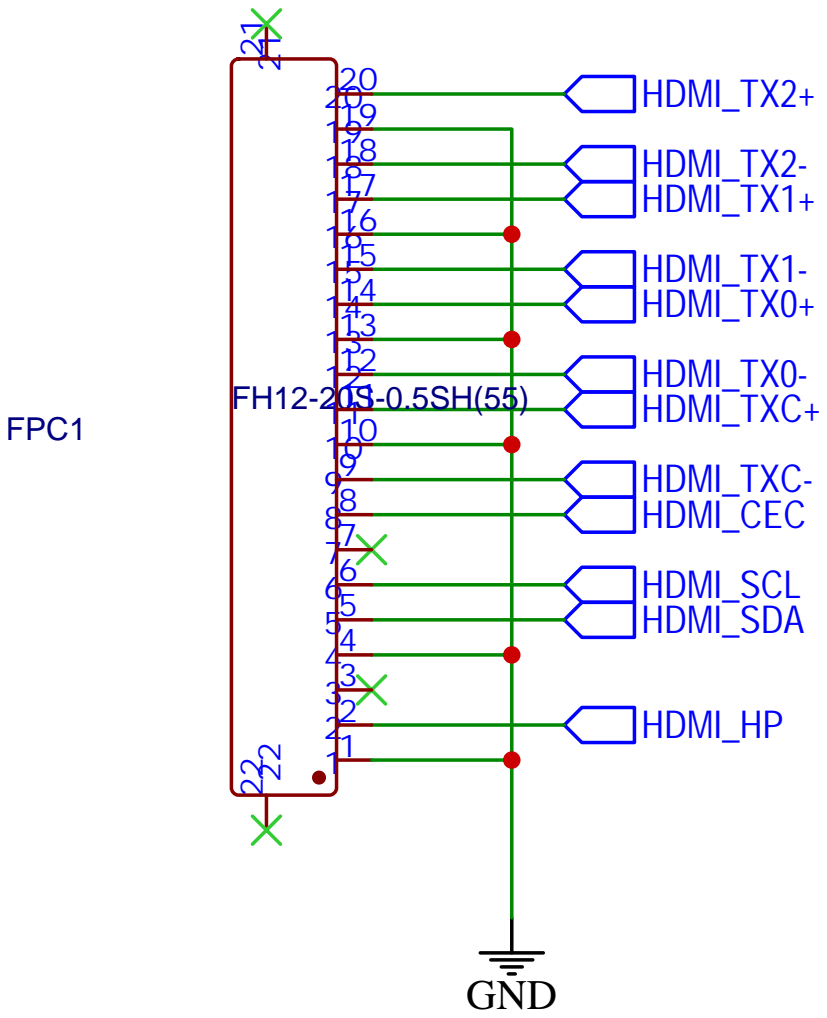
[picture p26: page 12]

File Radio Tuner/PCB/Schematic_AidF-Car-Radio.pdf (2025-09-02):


Drawn By: Aidan C Franits




For antenna connector, use RFU-523





DOUT 17 LRCK 18 BCK 19 SCKO 20


Volume/Balance/Fader Control


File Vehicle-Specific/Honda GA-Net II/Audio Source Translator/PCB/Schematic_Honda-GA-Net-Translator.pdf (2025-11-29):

Power Connector | +5V


Drawn By: Aidan C Franits





SN74HC595DRG4
SRCLR# 10 SRCLK 11 RCLK 12 OE# 13 SER 14 QA 15 VCC 16





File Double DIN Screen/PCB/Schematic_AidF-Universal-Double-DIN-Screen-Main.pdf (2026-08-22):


Drawn By: Aidan C Franits


## PINS 38 & 67

QO1 50 QO2 51QO3 52QO4 53QO5 54QO6 55QO7 56OVDD 57OGND 58QO8 59QO9 60QO10 61QO11 62QO12 63QO13 64QO14 65QO15 66DVDD 67GND 68QO16 69QO17 70QO18 71QO19 72QO20 73QO21 74QO22 75OGND 76QO23 77OVDD 78AGND 79Rx2+ 80Rx2- 81AVDD 82AGND 83AVDD 84Rx1+ 85Rx1- 86AGND 87AVDD 88AGND 89Rx0+ 90Rx0- 91AGND 92RxC+ 93RxC- 94AVDD 95EXT_RES 96PVDD 97PGND 98RSVD 99OCK_INV 100 101








## RED_O_7

## RED_O_6


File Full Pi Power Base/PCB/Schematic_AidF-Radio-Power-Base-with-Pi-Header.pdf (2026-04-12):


Drawn By: Aidan C Franits









P0B10 WP# 11 SHDN# 12 SDO 13 VDD 14


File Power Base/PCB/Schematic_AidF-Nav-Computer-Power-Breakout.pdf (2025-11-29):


Drawn By: Aidan C Franits








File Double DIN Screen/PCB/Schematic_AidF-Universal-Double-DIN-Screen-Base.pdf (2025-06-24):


Drawn By: Aidan C Franits






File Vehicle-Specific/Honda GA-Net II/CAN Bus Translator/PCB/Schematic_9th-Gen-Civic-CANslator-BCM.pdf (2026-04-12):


Drawn By: Aidan C Franits



## U20GND







# ILL_CATHODE_GATE ILL_POT_A¹ ILL_POT_B¹




Use with the ATCCPYDM CVBS to USB converter.




Use with Adafruit 746.



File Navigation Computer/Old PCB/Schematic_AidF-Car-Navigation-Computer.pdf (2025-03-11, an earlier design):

# LEDs /LED_ACTIVITY_GATE /LED_POWER_GATE


Drawn By: Aidan C Franits


Drawn By: Aidan C. Franits




## DAC

## DAC_MUTE






+AVDD +DVDD


Place C48 close to pin 1.
Place C49 close to pin 9.






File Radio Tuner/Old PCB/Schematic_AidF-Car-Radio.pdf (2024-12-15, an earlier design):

## PVDD: 3.3V DVDD: 3.3V


Drawn By: Aidan C Franits



## For antenna connector, use RFU-523





10 X_CH_3_IN/OUT 11 X_CH_0_IN/OUT 12 X_COMIN/OUT 13 X_CH_1_IN/OUT 14 X_CH_2_IN/OUT 15 VDD 16

## SRC_ANA_AUDIO_OUT_L

## ADC_OUT


DOUT 17 LRCK 18 BCK 19 SCKO 20

## Input Selection

For digital input, L acts as RX+ and R as RX-.


## Treble Control Bass Control


Volume/Balance/Fader Control


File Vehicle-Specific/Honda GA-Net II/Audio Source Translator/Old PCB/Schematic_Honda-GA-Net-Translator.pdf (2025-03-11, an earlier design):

## Power Connector


Drawn By: Aidan C Franits





SN74HC595DRG4
SRCLR# 10 SRCLK 11 RCLK 12 OE# 13 SER 14 QA 15 VCC 16

# GNDGA_ON_DRAIN



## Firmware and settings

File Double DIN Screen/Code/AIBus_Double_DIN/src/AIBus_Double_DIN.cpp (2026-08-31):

#include "AIBus_Double_DIN.h"

AIBusDoubleDIN aibus_double_din;

static const volatile uint8_t aibt_edid[] = {
	0x00, 0xFF, 0xFF, 0xFF, 0xFF, 0xFF, 0xFF, 0x00, 0x05, 0x24, 0x00, 0x01,
	0x01, 0x00, 0x00, 0x00, 0x01, 0x11, 0x01, 0x03, 0x81, 0x0E, 0x08, 0x78,
	0x2E, 0x35, 0x85, 0xA6, 0x56, 0x48, 0x9A, 0x24, 0x12, 0x50, 0x54, 0xAF,
	0xEF, 0x00, 0x01, 0x01, 0x01, 0x01, 0x01, 0x01, 0x01, 0x01, 0x01, 0x01,
	0x01, 0x01, 0x01, 0x01, 0x01, 0x01, 0x3E, 0x0D, 0x20, 0x00, 0x31, 0xE0,
	0x37, 0x10, 0x2C, 0x58, 0x36, 0x00, 0xDC, 0x0C, 0x11, 0x00, 0x00, 0x1E,
	0x00, 0x00, 0x00, 0xFC, 0x00, 0x41, 0x69, 0x64, 0x46, 0x20, 0x41, 0x49,
	0x42, 0x54, 0x0A, 0x20, 0x20, 0x20, 0x00, 0x00, 0x00, 0x10, 0x00, 0x00,
	0x00, 0x00, 0x00, 0x00, 0x00, 0x00, 0x00, 0x00, 0x00, 0x00, 0x00, 0x00,
	0x00, 0x00, 0x00, 0x10, 0x00, 0x00, 0x00, 0x00, 0x00, 0x00, 0x00, 0x00,
	0x00, 0x00, 0x00, 0x00, 0x00, 0x00, 0x00, 0xBA
};


volatile int static_vol_steps = 0, static_nav_steps = 0;
elapsedMillis static_vol_timer, static_nav_timer;

//Arduino setup.
void setup() {
	aibus_double_din.setup();
}

//Arduino loop.
void loop() {
	aibus_double_din.loop();
}

//Main object setup.
void AIBusDoubleDIN::setup() {
	this->vol_timer = &static_vol_timer;
	this->vol_steps = &static_vol_steps;
	this->nav_timer = &static_nav_timer;
	this->nav_steps = &static_nav_steps;

	pinMode(ILL_CS, OUTPUT);
	pinMode(ILL_ON, OUTPUT);
	pinMode(FULL_POWER_ON, OUTPUT);
	pinMode(MCP_RESET, OUTPUT);

	pinMode(OPEN_CLOSE_CS, OUTPUT);
	pinMode(BL_ON, OUTPUT);
	
	pinMode(BT_EJECT, INPUT_PULLUP);
	pinMode(BT_SOURCE, INPUT_PULLUP);
	pinMode(BT_AUDIO, INPUT_PULLUP);
	pinMode(BT_FMAM, INPUT_PULLUP);
	pinMode(BT_AUX, INPUT_PULLUP);
	pinMode(BT_SKIPUP, INPUT_PULLUP);
	pinMode(BT_SKIPDN, INPUT_PULLUP);
	pinMode(BT_INFO, INPUT_PULLUP);
	pinMode(BT_TONE, INPUT_PULLUP);
	pinMode(BT_HOME, INPUT_PULLUP);
	pinMode(BT_SETUP, INPUT_PULLUP);
	pinMode(BT_BACK, INPUT_PULLUP);

	pinMode(BT_F1, INPUT_PULLUP);
	pinMode(BT_F2, INPUT_PULLUP);
	pinMode(BT_F3, INPUT_PULLUP);
	pinMode(BT_F4, INPUT_PULLUP);
	pinMode(BT_F5, INPUT_PULLUP);
	pinMode(BT_F6, INPUT_PULLUP);

	pinMode(VOL_CLK, INPUT);
	pinMode(VOL_UP, INPUT);
	pinMode(NAV_CLK, INPUT);
	pinMode(NAV_UP, INPUT);
	pinMode(NAV_CS, OUTPUT);
	
	digitalWrite(ILL_CS, HIGH);
	digitalWrite(ILL_ON, LOW);
	digitalWrite(FULL_POWER_ON, HIGH);
	digitalWrite(MCP_RESET, HIGH);
	digitalWrite(NAV_CS, HIGH);
	digitalWrite(OPEN_CLOSE_CS, HIGH);
	digitalWrite(BL_ON, LOW);
	
	AISerial.begin(AI_BAUD);
	
	SPI.begin();
	delay(100);
	
	ill_mcp4251.begin();
	ill_mcp4251.DigitalPotSetWiperPosition(0,0);
	ill_mcp4251.DigitalPotSetWiperPosition(1,256);

	nav_mcp.begin();
	nav_mcp.pinModeIO(NAV_MCP_NAV_PUSH, INPUT_PULLUP);
	nav_mcp.pinModeIO(NAV_MCP_NAV_UP, INPUT_PULLUP);
	nav_mcp.pinModeIO(NAV_MCP_NAV_DN, INPUT_PULLUP);
	nav_mcp.pinModeIO(NAV_MCP_NAV_LEFT, INPUT_PULLUP);
	nav_mcp.pinModeIO(NAV_MCP_NAV_RIGHT, INPUT_PULLUP);
	nav_mcp.pinModeIO(NAV_MCP_VOL_PUSH, INPUT_PULLUP);
	
	nav_mcp.pinModeIO(NAV_MCP_ILL_AIDF, OUTPUT);
	nav_mcp.digitalWriteIO(NAV_MCP_ILL_AIDF, false);

	open_close_mcp.begin();
	open_close_mcp.pinModeIO(OC_MCP_OPEN_IND, INPUT_PULLUP);
	open_close_mcp.pinModeIO(OC_MCP_CLOSE_IND, INPUT_PULLUP);
	open_close_mcp.pinModeIO(OC_MCP_OPEN_TOG, OUTPUT);
	open_close_mcp.pinModeIO(OC_MCP_CLOSE_TOG, OUTPUT);

	open_close_mcp.digitalWriteIO(OC_MCP_OPEN_TOG, false);
	open_close_mcp.digitalWriteIO(OC_MCP_CLOSE_TOG, false);

	attachInterrupt(VOL_CLK, incVolume, FALLING);
	attachInterrupt(NAV_CLK, incNavigation, FALLING);

	uint8_t init_data[] = {0x4A, 0x1F};
	AIData init_msg(sizeof(init_data), ID_NAV_SCREEN, ID_CANSLATOR, init_data);
	ai_handler.writeAIData(&init_msg, false);

	/*Wire.begin(0x50);

	Wire.onReceive(receiveI2C);
	Wire.onRequest(handleEDID);
	
	for(int i=0;i<sizeof(aibt_edid);i+=1)
		Wire.write(aibt_edid[i]);*/

	uint8_t poweroff_data[] = {0xA0};
	AIData poweroff_msg(sizeof(poweroff_data), ID_NAV_SCREEN, 0xFF, poweroff_data);
	ai_handler.writeAIData(&poweroff_msg, false);

	digitalWrite(FULL_POWER_ON, LOW);
}

//Main object loop.
void AIBusDoubleDIN::loop() {
	AIData msg;
	elapsedMillis ai_timer = 0;
	bool first_msg = false;
	
	do {
		bool message_read = false;
		if(ai_handler.dataAvailable() > 0) {
			if(ai_handler.readAIData(&msg)) {
				if(msg.sender == ID_NAV_SCREEN)
					continue;

				if(msg.sender == ID_RADIO && !parameters.radio_connected)
					parameters.radio_connected = true;
				
				if(msg.sender == ID_NAV_COMPUTER && !parameters.computer_connected)
					parameters.computer_connected = true;

				if(msg.receiver == 0xFF && msg.l == 1 && msg[0] == 0x1) { //Ping.
					uint8_t ping_data[] = {0x1};
					AIData ping_msg(sizeof(ping_data), ID_NAV_SCREEN, msg.sender, ping_data);
					ai_handler.writeAIData(&ping_msg);
				} else if(msg.receiver == ID_NAV_SCREEN && msg.l >= 1 && msg.data[0] != 0x80)
					message_read = true;
				else if(msg.receiver == 0xFF && msg.l >= 1 && msg.data[0] == 0xA1) {
					if(msg.sender == ID_CANSLATOR && msg.l >= 0x4 && msg.data[1] == 0x10) { //Light control.
						const uint8_t brightness = msg.data[2];
						const bool light = (msg.data[3]&0x1) != 0;

						digitalWrite(ILL_ON, light ? HIGH : LOW);
						ill_mcp4251.DigitalPotSetWiperPosition(0, brightness < 255 ? brightness : 256);
						ill_mcp4251.DigitalPotSetWiperPosition(1, brightness < 255 ? brightness : 256);
					} else if(msg.sender == ID_CANSLATOR && msg.l >= 3 && msg.data[1] == 0x2) { //Key position.
						const uint8_t last_key = parameters.key_position;
						parameters.key_position = msg.data[2]&0xF;

						if(parameters.key_position != last_key) {
							if(parameters.key_position != 0) {
								digitalWrite(FULL_POWER_ON, HIGH);
								digitalWrite(BL_ON, HIGH);
								nav_mcp.digitalWriteIO(NAV_MCP_ILL_AIDF, audio_on);
								parameters.allow_open = true;
								key_on = true;
								door_timer_enabled = false;
							} else {
								if((parameters.door_position&0xC) != 0) {
									nav_mcp.digitalWriteIO(NAV_MCP_ILL_AIDF, false);

									parameters.allow_open = false;

									uint8_t poweroff_data[] = {0xA0};
									AIData poweroff_msg(sizeof(poweroff_data), ID_NAV_SCREEN, 0xFF, poweroff_data);
									ai_handler.writeAIData(&poweroff_msg, false);

									digitalWrite(FULL_POWER_ON, LOW);
									digitalWrite(BL_ON, LOW);
								} else {
									door_timer_enabled = true;
									door_timer = 0;
								}
							} 
						}
					} else if(msg.sender == ID_CANSLATOR && msg.l >= 3 && msg.data[1] == 0x43) { //Door opened or closed.
						const uint8_t last_door = parameters.door_position;
						parameters.door_position = msg.data[2];
						const uint8_t front_door_position = parameters.door_position&0xC;

						if(parameters.key_position == 0 && front_door_position != (last_door&0xC)) {
							const bool power_on = digitalRead(FULL_POWER_ON) != LOW;

							if(front_door_position != 0) {
								if(power_on || (parameters.door_position&0x80) != 0) {
									if(key_on || (parameters.door_position&0x80) != 0) {
										nav_mcp.digitalWriteIO(NAV_MCP_ILL_AIDF, false);

										uint8_t poweroff_data[] = {0xA0};
										AIData poweroff_msg(sizeof(poweroff_data), ID_NAV_SCREEN, 0xFF, poweroff_data);
										ai_handler.writeAIData(&poweroff_msg, false);

										parameters.allow_open = false;

										digitalWrite(FULL_POWER_ON, LOW);
										digitalWrite(BL_ON, LOW);
									}
								} else {
									digitalWrite(FULL_POWER_ON, HIGH);
									digitalWrite(BL_ON, HIGH);
									nav_mcp.digitalWriteIO(NAV_MCP_ILL_AIDF, audio_on);
									door_timer_enabled = true;
									door_timer = 0;
								}
							}
						}
					}
				}
			}

			if(message_read) {
				if(msg.sender == ID_NAV_SCREEN)
					continue;

				if(msg.l >= 2 && msg.data[0] == 0x31 && msg.data[1] == 0x30) { //Button request.
					sendButtonsPresent(msg.sender);
				} else if(msg.l >= 3 && msg.data[0] == 0x77) { //Control change.
					const uint8_t controls = msg.data[2], receiver = msg.data[1];
					if((controls&0x10) != 0) { //Full screen control.
						all_timer_enabled = true;
						all_timer = 0;
						parameters.all_dest = receiver;

						if(!radio_timer_enabled || parameters.audio_dest == receiver) {
							radio_timer_enabled = true;
							radio_timer = 0;
							parameters.audio_dest = receiver;

							if(!source_timer_enabled || parameters.source_dest == receiver) {
								source_timer_enabled = true;
								source_timer = 0;
								parameters.source_dest = receiver;
							}
						}
					}

					if((controls&0x20) != 0) { //Audio control.
						radio_timer_enabled = true;
						radio_timer = 0;
						parameters.audio_dest = receiver;

						if(!source_timer_enabled || parameters.source_dest == receiver) {
							source_timer_enabled = true;
							source_timer = 0;
							parameters.source_dest = receiver;
						}
					}

					if((controls&0x80) != 0) { //Source control.
						source_timer_enabled = true;
						source_timer = 0;
						parameters.source_dest = receiver;
					}
				} else if(msg.l >= 2 && msg.data[0] == 0x38) { //Open/close.
					const uint8_t command = msg.data[1];
					if(command == 0)
						open_handler.setClosed();
					else if(command == 2)
						open_handler.setOpen();
				} else if(msg.l >= 4 && msg.data[0] == 0x33) { //Forward.
					const uint8_t dest = msg.data[1], button = msg.data[2], state = msg.data[3];
					uint8_t button_data[] = {0x30, button, state};
					AIData button_msg(sizeof(button_data), ID_NAV_SCREEN, dest, button_data);

					ai_handler.writeAIData(&button_msg);
				} else if(msg.l >= 2 && msg.data[0] == 0x34) { //AidF logo on/off.
					const bool logo_on = msg.data[1] != 0;
					nav_mcp.digitalWriteIO(NAV_MCP_ILL_AIDF, logo_on);
					audio_on = logo_on;
				} else if(msg.sender == ID_NAV_COMPUTER && msg.l >= 2 && msg[0] == 0x10) { //Screen on/off.
					const bool on = msg[1] != 0x0;
					digitalWrite(BL_ON, on ? HIGH : LOW);
				} else if(msg.l >= 2 && msg.data[0] == 0x3E && msg.data[1] == 0xF0) { //EDID request.
					AIData edid_msg(sizeof(aibt_edid) + 1, ID_NAV_SCREEN, msg.sender);
					edid_msg[0] = 0x3E;
					for(int i=0;i<sizeof(aibt_edid);i+=1)
						edid_msg[i+1] = aibt_edid[i];
					
					ai_handler.writeAIData(&edid_msg);
				} else if(msg.l >= 2 && msg.data[0] == 0x2C && msg.data[1] == 0xF0) { //Screen resolution request.
					const uint16_t w = 800, h = 480;
					uint8_t resolution_data[] = {0x2C, w>>8, w&0xFF, h>>8, h&0xFF};
					AIData resolution_msg(sizeof(resolution_data), ID_NAV_SCREEN, msg.sender, resolution_data);
					ai_handler.writeAIData(&resolution_msg);
				}
			}

			if(!first_msg) {
				ai_timer = 0;
				first_msg = true;
			}
		}
	} while(ai_timer < 50);

	const uint8_t nav_states = nav_mcp.getInputStates();
	for(int i=0;i<TOGGLE_INDEX_SIZE;i+=1) {
		if(i<TOGGLE_INDEX_SIZE - 1)
			button_handler.toggle[i] = (nav_states&bit(i)) != 0;
		else
			button_handler.toggle[i] = (nav_states&0x80) != 0;
	}

	button_handler.loop();
	open_handler.loop();
	
	if((*vol_timer > VOL_TIMER || abs(*vol_steps) >= 0xF) && *vol_steps != 0) {
		setVolume(parameters.audio_dest);
		*vol_timer = 0;
		*vol_steps = 0;
	}
	
	if((*nav_timer > VOL_TIMER || abs(*nav_steps) >= 0xF) && *nav_steps != 0) {
		setNavigation(parameters.all_dest);
		*nav_timer = 0;
		*nav_steps = 0;
	}

	if(door_timer_enabled && door_timer > DOOR_TIMER && parameters.key_position == 0) {
		door_timer_enabled = false;
		nav_mcp.digitalWriteIO(NAV_MCP_ILL_AIDF, false);

		uint8_t poweroff_data[] = {0xA0};
		AIData poweroff_msg(sizeof(poweroff_data), ID_NAV_SCREEN, 0xFF, poweroff_data);
		ai_handler.writeAIData(&poweroff_msg, false);

		digitalWrite(FULL_POWER_ON, LOW);
		digitalWrite(BL_ON, LOW);
	}

	if(all_timer_enabled && all_timer > CONTROL_TIMER) {
		all_timer_enabled = false;
		parameters.all_dest = ID_NAV_COMPUTER;
	}

	if(radio_timer_enabled && radio_timer > CONTROL_TIMER) {
		radio_timer_enabled = false;
		parameters.audio_dest = ID_NAV_COMPUTER;

		if(all_timer_enabled)
			parameters.audio_dest = parameters.all_dest;
		else
			parameters.audio_dest = ID_NAV_COMPUTER;
	}

	if(source_timer_enabled && source_timer > CONTROL_TIMER) {
		source_timer_enabled = false;
		if(radio_timer_enabled)
			parameters.source_dest = parameters.audio_dest;
		else if(all_timer_enabled)
			parameters.source_dest = parameters.all_dest;
		else
			parameters.source_dest = ID_NAV_COMPUTER;
	}
}

//Respond to a button query.
void AIBusDoubleDIN::sendButtonsPresent(const uint8_t receiver) {
	uint8_t button_data[] = {0x31, 0x30, 0x16, 0x6, 0x7, 0x23, 0x26, 0x36, 0x38, 0x25, 0x24, 0x53, 0x52, 0x20, 0x51, 0x27, 0x11, 0x12, 0x13, 0x14, 0x15, 0x16, 0x28, 0x29, 0x2A, 0x2B};
	AIData button_msg(sizeof(button_data), ID_NAV_SCREEN, receiver, button_data);

	ai_handler.writeAIData(&button_msg);
}

//Send a volume message.
void AIBusDoubleDIN::setVolume(const uint8_t receiver) {
	while(abs(*vol_steps) > 0) {
		uint8_t vol_data[] = {0x32, 0x6, abs(*vol_steps)&0xF};
		if(*vol_steps > 0)
			vol_data[2] |= 0x10;

		AIData vol_msg(sizeof(vol_data), ID_NAV_SCREEN, receiver, vol_data);

		bool ack = true;
		if(receiver == ID_NAV_COMPUTER && !parameters.computer_connected)
			ack = false;
		else if(receiver == ID_RADIO && !parameters.radio_connected)
			ack = false;
		else if(receiver == 0xFF || receiver == ID_NAV_SCREEN)
			ack = false;
		
		ai_handler.writeAIData(&vol_msg, ack);

		if(abs(*vol_steps) <= 0xF)
			*vol_steps = 0;
		else {
			if(*vol_steps > 0)
				*vol_steps -= 0xF;
			else
				*vol_steps += 0xF;
		}

		ai_handler.cachePending(ID_NAV_SCREEN);
	}

	*vol_steps = 0;
}

//Send a nav knob message.
void AIBusDoubleDIN::setNavigation(const uint8_t receiver) {
	while(abs(*nav_steps) > 0) {
		uint8_t nav_data[] = {0x32, 0x7, abs(*nav_steps)&0xF};
		if(*nav_steps > 0)
			nav_data[2] |= 0x10;

		AIData nav_msg(sizeof(nav_data), ID_NAV_SCREEN, receiver, nav_data);

		bool ack = true;
		if(receiver == ID_NAV_COMPUTER && !parameters.computer_connected)
			ack = false;
		else if(receiver == ID_RADIO && !parameters.radio_connected)
			ack = false;
		else if(receiver == 0xFF || receiver == ID_NAV_SCREEN)
			ack = false;

		ai_handler.writeAIData(&nav_msg, ack);

		if(abs(*nav_steps) <= 0xF)
			*nav_steps = 0;
		else {
			if(*nav_steps > 0)
				*nav_steps -= 0xF;
			else
				*nav_steps += 0xF;
		}

		ai_handler.cachePending(ID_NAV_SCREEN);
	}

	*nav_steps = 0;
}

//Increment the volume function.
void incVolume() {
	if(static_vol_steps == 0)
		static_vol_timer = 0;
		
	const bool cw = digitalRead(VOL_UP) != LOW;
	if(cw)
		static_vol_steps += 1;
	else
		static_vol_steps -= 1;
}

//Increment the navigation function.
void incNavigation() {
	if(static_nav_steps == 0)
		static_nav_timer = 0;

	const bool cw = digitalRead(NAV_UP) == LOW;
	if(cw)
		static_nav_steps += 1;
	else
		static_nav_steps -= 1;
}

//Called when an I2C message is received.
void receiveI2C(int byte_count) {
	while(Wire.available())
		Wire.read();
}

//Send EDID data.
void handleEDID() {
	for(int i=0;i<sizeof(aibt_edid);i+=1)
		Wire.write(aibt_edid[i]);
}

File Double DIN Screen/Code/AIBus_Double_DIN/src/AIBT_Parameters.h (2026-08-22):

#include <Arduino.h>
#include <elapsedMillis.h>

#include "AIBus.h"

#ifndef parameter_list_h
#define parameter_list_h

#ifdef MEGACOREX
#define BT_EJECT PIN_PC0
#define BT_SOURCE PIN_PC1
#define BT_AUDIO PIN_PC2
#define BT_FMAM PIN_PC3
#define BT_AUX PIN_PC4
#define BT_SKIPUP PIN_PC5
#define BT_SKIPDN PIN_PC6
#define BT_INFO PIN_PC7
#define BT_TONE PIN_PD0
#define BT_HOME PIN_PD1
#define BT_SETUP PIN_PD2
#define BT_BACK PIN_PD3

#define BT_F1 PIN_PD4
#define BT_F2 PIN_PD5
#define BT_F3 PIN_PD6
#define BT_F4 PIN_PD7
#define BT_F5 PIN_PE0
#define BT_F6 PIN_PE1
#else
#define BT_EJECT 9
#define BT_SOURCE 10
#define BT_AUDIO 11
#define BT_FMAM 12
#define BT_AUX 13
#define BT_SKIPUP 14
#define BT_SKIPDN 15
#define BT_INFO 16
#define BT_TONE 17
#define BT_HOME 18
#define BT_SETUP 19
#define BT_BACK 20

#define BT_F1 21
#define BT_F2 22
#define BT_F3 23
#define BT_F4 24
#define BT_F5 25
#define BT_F6 26
#endif

#define BUTTON_INDEX_SIZE 18

#define BUTTON_STATE_RELEASED 0
#define BUTTON_STATE_PRESSED 1
#define BUTTON_STATE_HELD 2

struct ParameterList {
	bool radio_connected = false, computer_connected = false;

	uint8_t key_position = 0, door_position = 0;
	bool allow_open = false; //True if the screen can be opened, i.e. the car is on.

	uint8_t all_dest = ID_NAV_COMPUTER, audio_dest = ID_NAV_COMPUTER, source_dest = ID_NAV_COMPUTER;
};

#endif

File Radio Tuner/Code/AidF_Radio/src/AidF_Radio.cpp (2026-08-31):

#include "AidF_Radio.h"

AidFRadio aidf_radio;

//AVR setup.
void setup() {
	aidf_radio.setup();
}

//AVR loop.
void loop() {
	aidf_radio.loop();
}

//Main class setup.
void AidFRadio::setup() {
	pinMode(AI_RX, INPUT_PULLUP);
	
	pinMode(TUNER_RESET, OUTPUT);

	pinMode(AUDIO_SW, OUTPUT);
	pinMode(NAV_SW, OUTPUT);
	pinMode(AUDIO_ON_SW, OUTPUT);
	pinMode(POWER_ON_SW, OUTPUT);
	pinMode(AUX_SW, INPUT_PULLUP);
	pinMode(NAV_MUTE, INPUT_PULLUP);

	pinMode(DAC_FILTER_MODE, OUTPUT);
	pinMode(DAC_MUTE, OUTPUT);

	pinMode(VOL_CS, OUTPUT);
	pinMode(TREBLE_CS, OUTPUT);
	pinMode(BASS_CS, OUTPUT);
	pinMode(FADE_CS, OUTPUT);
	pinMode(ADC_CS, OUTPUT);

	pinMode(RAM_CS, OUTPUT);

	pinMode(DIGITAL_ERROR, INPUT);
	
	digitalWrite(TUNER_RESET, HIGH);
	digitalWrite(NAV_SW, LOW);

	digitalWrite(AUDIO_SW, LOW);

	digitalWrite(AUDIO_ON_SW, LOW);
	digitalWrite(POWER_ON_SW, HIGH);

	digitalWrite(DAC_FILTER_MODE, LOW);
	digitalWrite(DAC_MUTE, LOW);
	digitalWrite(ADC_CS, HIGH);

	digitalWrite(RAM_CS, HIGH);

	#if defined(DXCORE)
	SPI.swap(SPI0_SWAP_DEFAULT);
	Wire.swap(0);
	Wire.usePullups();
	#endif

	AISerial.begin(AI_BAUD);
	Wire.begin();
	SPI.begin();
	delay(10);
	sram_handler.begin();

	tuner.init1();
	br_tuner.init1();
	tuner.init2();
	br_tuner.init2();

	br_tuner.setPower(true, SUB_FM1);

	parameters.fm1_tune = tuner.getFrequency();
	parameters.fm2_tune = tuner.getFrequency();
	parameters.am_tune = parameters.am_start;

	getEEPROMPresets(&parameters);
	normalizePresets();
	setEEPROMPresets(&parameters);

	parameters.handshake_sources.setStorage(parameters.handshake_source_list, 0);

	volume_handler.init();
	adc_handler.init();

	AudioSource src_fm1, src_fm2, src_am;
	src_fm1.source_name = "FM1";
	src_fm1.source_short = "FM1";
	src_fm1.source_id = ID_RADIO;
	src_fm1.sub_id = 0;
	src_fm1.connected = true;
	src_fm2.source_name = "FM2";
	src_fm2.source_short = "FM2";
	src_fm2.source_id = ID_RADIO;
	src_fm2.sub_id = 1;
	src_fm2.connected = true;
	src_am.source_name = "AM";
	src_am.source_short = "AM";
	src_am.source_id = ID_RADIO;
	src_am.sub_id = 2;
	src_am.connected = true;

	AudioSource src_aux;
	src_aux.source_name = "Aux";
	src_aux.source_short = "Aux";
	src_aux.source_id = ID_RADIO;
	src_aux.sub_id = 3;
	src_aux.connected = true;

	source_handler.source_list[0] = src_fm1;
	source_handler.source_list[1] = src_fm2;
	source_handler.source_list[2] = src_am;

	source_handler.source_list[SOURCE_COUNT - 3] = src_aux;

	if(sram_handler.getValid()) { //Populate params.
		StartParams start_params;
		sram_handler.getStartParams(&start_params);
		sram_handler.getFrequencies(&background_tuner);
		sram_handler.getRAMPresets(&parameters);
		normalizePresets();
		setEEPROMPresets(&parameters);

		const uint8_t source_count = sram_handler.getSourceCount();
		AudioSource source_list[source_count];
		sram_handler.getSources(source_count, source_list);

		int li = 0;

		for(int s=0;s<source_count;s+=1) {
			bool list_full = false;
			while(source_handler.source_list[li].source_id != 0) {
				li += 1;
				if(li > source_handler.source_count) {
					list_full = true;
					break;
				}
			}
			if(list_full)
				break;

			if(source_list[s].source_id != ID_RADIO && source_list[s].source_id != 0x0) {
				source_handler.source_list[li] = source_list[s];
				uint8_t ping_data[] = {0x1};
				AIData ping_msg(sizeof(ping_data), ID_RADIO, source_list[s].source_id, ping_data);
				aibus_handler.writeAIData(&ping_msg, false);
			}
		}

		int index = -1;
		const int final_source_count = source_handler.source_count;

		for(int s=0;s<final_source_count;s+=1) {
			if(source_handler.source_list[s].source_id == start_params.selected_source && source_handler.source_list[s].sub_id == start_params.selected_subsource)
				index = s;
		}

		if(index >= 0)
		 	source_handler.setSource(index);

		source_handler.setAudioOn(start_params.audio_on);
		if(start_params.audio_on)
			digitalWrite(DAC_MUTE, HIGH);
		
		parameters.am_tune = start_params.am_freq;
		parameters.fm1_tune = start_params.fm1_freq;
		parameters.fm2_tune = start_params.fm2_freq;

		parameters.clock_freq = start_params.clock_freq;

		parameters.send_time = false;
		if((start_params.clock_mode&CLOCK_MODE_BROADCAST_AUTO) != 0) {
			parameters.auto_clock = true;
			parameters.send_time = true;
		}
		if((start_params.clock_mode&CLOCK_MODE_BROADCAST_MANUAL) != 0) {
			parameters.auto_clock = false;
			parameters.send_time = true;
		}
		if((start_params.clock_mode&CLOCK_MODE_RTC_INIT) != 0)
			rtc_on = true;

		if((start_params.clock_mode&CLOCK_MODE_12H) != 0)
			parameters.send_12h = true;

		parameters.header_rds_setting = start_params.rds_setting;
		
		volume_handler.setVolume(start_params.vol);
		volume_handler.setVolRange(start_params.max_vol);
		volume_handler.setTreble(start_params.treble);
		volume_handler.setBass(start_params.bass);
		volume_handler.setBalance(start_params.balance);
		volume_handler.setFader(start_params.fader);

		parameters.source_button_mode = start_params.source_button_setting;
		parameters.aux_level = start_params.aux_level;
		parameters.prompt_cut = start_params.nav_cut > 0 ? start_params.nav_cut : 2;
		parameters.dac_filter_mode = start_params.dac_latency;
		parameters.steering_control_preset = start_params.steering_control_preset;

		parameters.svc = start_params.svc_setting;
	}
	
	if(rtc.autoprobe()) { //Start/set the clock.
		rtc.enableBatteryBackup();
		rtc.startClock();
		rtc.setSQW(RTCx::freq32768Hz);
		rtc.setCalibration(0);

		if(rtc_on) {
			RTCx::tm rtc_time;

			rtc.readClock(&rtc_time, RTCx::TIME);
			parameters.hour = rtc_time.tm_hour;
			parameters.min = rtc_time.tm_min;
			parameters.minute_timer = rtc_time.tm_sec*1000;
		}

		rtc_on = true;
	}

	tuner.setLimits();
	background_tuner.setLimits();

	phone_active_vec.setStorage(phone_active_list);

	uint8_t init_data[] = {0x4A, 0x1F};
	AIData init_msg(sizeof(init_data), ID_RADIO, ID_CANSLATOR, init_data);
	aibus_handler.writeAIData(&init_msg, false);
	aibus_handler.flush();

	powerOff();
}
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

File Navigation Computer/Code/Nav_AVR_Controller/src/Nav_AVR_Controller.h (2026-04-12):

#include <stdint.h>
#include <Arduino.h>
#include <elapsedMillis.h>

#include "AIBus_Handler.h"

#ifndef nav_avr_controller_h
#define nav_avr_controller_h

#ifdef MEGACOREX
#define PI_POWER PIN_PA2
#define POWER_ON PIN_PA3
#define PI_RUNNING PIN_PA4
#ifdef PI_CM
#define PI_BOOT PIN_PA5
#define PI_OFF_HARDWARE PIN_PA6
#define PI_OFF_SOFT PIN_PA7
#endif
#define AI_RX PIN_PC0
#ifdef PI_CM
#define PROG PIN_PC1
#endif
#define UART_DTR PIN_PC2
#else
#define PI_POWER 2
#define POWER_ON 3
#define PI_RUNNING 4
#ifdef PI_CM
#define PI_BOOT 5
#define PI_OFF_HARDWARE 6
#define PI_OFF_SOFT 7
#endif
#define AI_RX 8
#ifdef PI_CM
#define PROG 9
#endif
#define UART_DTR 10
#endif

#define DOOR_TIMER 30000
#define PI_BOOT_TIMER 20

#define PI_PING_TIMER 10000

#define AISerial Serial

class NavAVRController {
public:
	void setup();
	void loop();
private:
	AIBusHandler ai_handler = AIBusHandler(&AISerial, AI_RX, ID_COMPUTER_PROXY);

	uint8_t key_position = 0, door_position = 0;
	bool pi_on = false, shutdown = false;
	bool boot = false, run = false;
	bool key_on = false; //True if the key has been in the on position at any time during this power cycle.

	elapsedMillis shutdown_timer = 0;
	bool use_shutdown_timer = false;

	elapsedMillis door_timer = 0;
	bool door_timer_enabled = false;

	elapsedMillis pi_boot_timer = 0;
	bool boot_timer_enabled = false;

	elapsedMillis pi_ping_timer = 0;
	bool computer_connected = false;

	void powerOn();
	void powerOff();
};

void setup();
void loop();

#endif

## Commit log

2024-08-10 8th Gen Civic Screen Mechanism
    [8th Gen AIBT Front.FCStd, 8th Gen AIBT Front.stl, BOM_8th-gen-Civic-Navigation-Screen-AIBT-Base.csv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]
2024-08-11 Screen Bug Fixes
    Fixed a design error in the screen front board.
    [Navi_8th_AIBT.ino]
2024-08-13 Screen Integration
    Added screen integration to the radio, also changed the screen buttons to active low.
2024-08-13 Volume Knob
    Volume knob and power control.
2024-08-17 PWM Fix
    PWM Code Fix
    [Navi_8th_AIBT.ino]
2024-08-18 IEBus Interrupt Protection
    Added extra protection for the serial input to fix a bug.
    [Parameter_List.h]
2024-08-18 Bug Fix Attempts
    Trying to fix some bugs...
    [Navi_8th_AIBT.ino]
2024-08-20 Screen Integration Bug Fixes
    Fixed some bugs that came with screen integration.
    [Navi_8th_AIBT.ino]
2024-08-20 Radio Button Support
    Added source/function button support on the radio.
2024-08-23 AIBus Handler Update
    Fixed a bug in the AIBus handler.
    [8th Gen AIBT Front.FCStd]
2024-08-24 Fixed Formatting
    Replaced spaces with tabs.
    [Vehicle_Info_Parameters.h]
2024-09-07 Si4735 Radio Coding
    The final design will use an Si4735 as the main tuner, which uses different I2C commands than the Si4703.
    [Radio Nav Enclosure.FCStd]
2024-09-14 Tuner Parts and Motor Movement Detection
    Added universal tuner parts and motor movement detection code in the 8th generation CIvic navigation screen.
    [BOM_AidF-Car-Radio_2024-09-14.csv, BOM_DigiKey_AidF-Car-Radio.csv]
2024-09-21 Bluetooth and RDS
    Added a Bluetooth device class and started RDS querying.
2024-10-05 Nav SDL to Rust Socket
    Added socket functions in the main nav code.
2024-10-06 Reliable Socket AIBus
    Made the socket AIBus transmissions a bit more reliable.
2024-10-12 Phone Mirroring Audio
    Added support for phone mirroring audio.
    [BOM_AidF-Car-Radio.csv, BOM_AidF-Car-Radio_2024-09-14.csv, BOM_DigiKey_AidF-Car-Radio.csv]
2024-10-17 General Bug Fixes
    General bug fixes and enhancements.
    [AidF_Nav_Computer_Pi.cpp, main.rs]
2024-10-19 IMID Info Enhancements
    Enhanced the functionality of the "info" button on Honda CD changers and XM tuners for multi-line screens.
2024-11-01 Radio Station List!
    Radio station list feature works with the second tuner.
    [BOM_AidF-Phone-Control-Module.csv]
2024-11-16 General Enhancements
    General enhancements including ROM settings recovery, ADC handling, and more.
    [BOM_DigiKey_AidF-Phone-Control-Module.csv]
2024-12-15 Tone Menu
    Added support for a tone menu for the radio.
    [BOM_AidF-Car-Radio.csv, BOM_DigiKey_AidF-Car-Radio.csv]
2024-12-24 Text Splitting
    Added support for split text across all sources.
    [BOM_AidF-Car-Navigation-Computer.csv, BOM_DigiKey_AidF-Car-Navigation-Computer.csv]
2025-01-12 Fixes and Enhancements
    Various bug fixes and enhancements.
    [AidF_Nav_Computer_Pi.cpp]
2025-01-24 AIBus Threading
    Added AIBus threading to the AA mirror.
2025-01-24 Acknowledgement Bug Fix
    Acknowledgement bug fix.
    [main.rs]
2025-01-29 Honda Screen Front
    Revised the front of the Honda screen.
    [8th Gen AIBT Front.stl, BOM_8th-gen-Civic-Navigation-Screen-AIBT-Front.csv]
2025-02-08 Various Enhancements
    Added hybrid power flow arrows, audio window bug fixes, Android Auto communication with the Honda IMID, etc.
    [BOM_AidF-Car-Navigation-Computer.csv, BOM_DigiKey_AidF-Car-Navigation-Computer.csv]
2025-02-17 General Fixes
    General fixes and enhancements.
    [AidF_Nav_Computer_Pi.cpp, Navi_8th_AIBT.ino]
2025-03-11 General Updates
    General code and module updates.
    [BOM_AidF-Phone-Control-Module.csv, BOM_Honda-GA-Net-Translator.csv]
2025-06-05 Project Reboot
    The project has been rebooted and the screen is, for the most part, ready to build.
    [141_TS0101F020P.stp, Double DIN Screen 5 Inch.FCStd, Double DIN Screen Motorized 6 Inch Original.FCStd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]
2025-06-24 Updates
    General updates and enhancements.
    [BOM_AidF-Car-Radio.csv, BOM_AidF-Universal-Double-DIN-Screen-Base.csv, BOM_AidF-Universal-Double-DIN-Screen-Knobs.csv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]
2025-07-30 Updates
    General updates and fixes.
    [BOM_AidF-Car-Navigation-Computer.csv, BOM_AidF-Car-Radio.csv, BOM_AidF-Universal-Double-DIN-Screen-Gamma-Correction.csv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]
2025-08-17 Color Selection Memory
    The nav computer now recalls the last color scheme used on startup.
    [BOM_Honda-GA-Net-Translator.csv]
2025-08-30 Memory Leakage Bug Fixed
    Fixed a memory leakage bug in the nav computer software.
    [BOM_AidF-Car-Navigation-Computer.csv, BOM_AidF-Car-Navigation-Computer_JLC.csv, PickAndPlace_PCB_AidF-Car-Navigation-Computer.csv]
2025-09-02 Overlay Symbols
    Fixed an issue with overlay symbols in the phone mirror.
    [AidF_Nav_Computer_Pi.cpp]
2025-09-09 Enhancements
    General enhancements and fixes.
    [AidF_Nav_Computer_Pi.cpp]
2025-09-25 PlatformIO Architecture
    All Arduino-based components of this project now use PlatformIO for easier editing in VSCode and VSCodium.
    [BOM_AidF-Nav-Computer-Power-Breakout.csv]
2025-10-13 Various Enhancements
    Various enhancements including a complete set of Android Auto messages, locales (to prepare for language selection), and bug fixes.
    [BOM_Honda-GA-Net-Translator.csv]
2025-10-18 Android Bug Fixes
    Bug fixes for Android Auto.
    [BOM_Honda-GA-Net-Translator.csv]
2025-11-02 Locale Handling
    Added locale handling for multiple language support on multiple devices.
    [BOM_AidF-Nav-Computer-Power-Breakout.csv, BOM_AidF-Nav-Computer-S-PDIF-Receiver.csv]
2025-11-29 Bluetooth Handler
    Started work on the Bluetooth handler.
    [BOM_AidF-Nav-Computer-Power-Breakout.csv, BOM_AidF-Phone-Control-Module.csv, BOM_DigiKey_AidF-Phone-Control-Module.csv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]
2025-12-16 EDID Check
    Added a check for EDID so the video signal is correct even if EDID is not supported by HDMI.
    [AIBus_Double_DIN.cpp, AidF_Nav_Computer_Pi.cpp, Aux_Light_Control.cpp]
2026-01-05 Bug Fixes
    General enhancements.
    [BOM_AidF-Car-Navigation-Computer.csv, GA-Net Translator Enclosure.FCStd, PickAndPlace_PCB_AidF-Car-Navigation-Computer.csv]
2026-01-24 Bug Fixes
    Bug fixes and enhancements.
    [AIBus_Double_DIN.cpp, AidF_Nav_Computer_Pi.cpp, AidF_Radio.cpp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]
2026-04-18 Video Socket Handling
    Added a separate video socket to the nav UI.
2026-04-22 Aspect Ratio Bug Fixed
    Fixed an aspect ratio bug.
    [AidF_Nav_Computer_Pi.cpp]
2026-04-25 Bug Fixes
    General bug fixes.
    [AidF_Nav_Computer_Pi.cpp, Nav_AVR_Controller.cpp]
2026-05-27 Bluetooth Connectivity
    Added Bluetooth connectivity features.
    [BOM_AidF-Universal-Double-DIN-Screen-Main.csv, Test Print Buttons.3mf]
2026-06-07 Screen Panel and Bluetooth
    Adjustments to the screen CAD files and Bluetooth.
    [Double DIN Screen Motorized 6 Inch-Screen Panel.3mf, Double DIN Screen Motorized 6 Inch.FCStd, Test Print Buttons.3mf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]
2026-08-22 Backup Camera, Bug Fixes
    Rudimentary backup camera support has been added, though I haven't been able to successfully test it.
    [BOM_9th-Gen-Civic-CANslator-BCM.csv, Base Bottom Test.3mf, CANslator Enclosure Print.3mf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]
2026-10-07 Staggered Acknowledgment
    Added the ability to stagger acknowledgment when threading is not available. Also splitting the GA-NET CD changer into two MCUs, one to handle the GA-NET read/write.
2026-10-08 Phone Mirror Threaded AIBus
    Added threading to both directions of AIBus for the phone mirror.
2026-10-23 Phone Mirror Bug Fixes
    Phone mirror and camera bug fixes and enhancements.
